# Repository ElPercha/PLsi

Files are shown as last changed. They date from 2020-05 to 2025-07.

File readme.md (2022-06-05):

## **PLsi Project Objectives**

Create a PLC & HMI with the following main characteristics:
+ To not require external systems such us Laptops or Cellphones to be programmed
+ To be used on Classroom for educational purposes, IoT applications or industrial low risk applications
+ Software and Hardware with Industrial performance and features
+ Forever Open Source and Open Hardware
+ Focus on Low Cost, V0 hardware estimated in less than [$20](hard/CPU/v0/)

-----------------------------------------------------------------------------------------

## Hardware Version 0

**Main characteristics:**

- Easy to build, no SMD components. DIY!
- ESP32 Processor
	+ Dual Core @240MHZ
	+ Wi-Fi connectivity
- 2.8" 320x240 Touchscreen Display
- 8 Hardware Inputs 5-24VDC Isolated with status led
- 6 Hardware Relay Outputs with status led. Max 10A, external fuse required
- Different combinations of Digital and Analog I/O using the same board
	+ Analog I/O range: 0-5V 
- Removable Terminal blocks
- USB 5Vdc main power supply
- I2C port for hardwired expansions
- SD Card slot
- 3D printed housing model including DIN rail mounting bracket

-----------------------------------------------------------------------------------------

## Firmware Version 0.00.03

**Main functionalities:**

- PLC Ladder Logic Instruction set: 
	+ 35 instructions
	+ Boolean instructions full set
	+ Timers and Counters full set
	+ Comparisons full set
	+ 16 bit math functions
- PLC Memory Areas:
	+ 2000 Marks (M)
	+ 200 Counters (C) 
	+ 300 Timers (T)
	+ 10000 Registers 16bits (D)
- PLC Program size:
	+ Up to 400 networks of 6x5 cells (12K boolean instructions)
	+ Up to 4 PLC programs stored on internal memory (max. 400 networks each)
- PLC Program Editor
	+ Online Edition (with PLC running)
	+ Row, Column and Network Editor
	+ Network Navigation
- PLC performance and control
	+ Scan time of 2.3ms for 2000 Boolean instructions
	+ Processor Core 1 runs Ladder Logic exclusively
	+ RUN/STOP with user confirmation
- Display functions:
	+ PLC Programming and debugging
	+ PLsi Configuration
	+ HMI
		- "Fix" version implemented (User cannot edit memory areas nor texts)
		- Screen 1: 8 Switches M500 to M507
		- Screen 2: 8 Buttons  M510 to M517
		- Screen 3: 8 User Input Values D500 to D507 
		- Screen 4: Local I/O visualization
		- Screen 5: 8 Indicators M520 to M527
- Communications:
	+ Wi-Fi configuration. Only DHCP
	+ SSID scanning functionality
- Firmware update via Web Page
- Analog Inputs and Outputs
	+ Selectable via Configuration page

-----------------------------------------------------------------------------------------

## PLsi v0 Documentation

Build your own unit: [PLsi v0 Hardware Manual](./doc/PLsi_v0_Hardware_Manual.pdf)

Wiring, configuration and programming: [PLsi v0 User Manual](./doc/PLsi_v0_User_Manual.pdf) (on contruction)

 <!---
Or watch the Youtube videos: 
 + [Building a PLsi v0 - EN](https://www.youtube.com)
 + [Building a PLsi v0 - SP](https://www.youtube.com)
 + [Configuring and Programming a PLsi v0 - EN](https://www.youtube.com)
 + [Configuring and Programming a PLsi v0 - SP](https://www.youtube.com)
-->
-----------------------------------------------------------------------------------------

## PLsi v0 Comparison with similar products

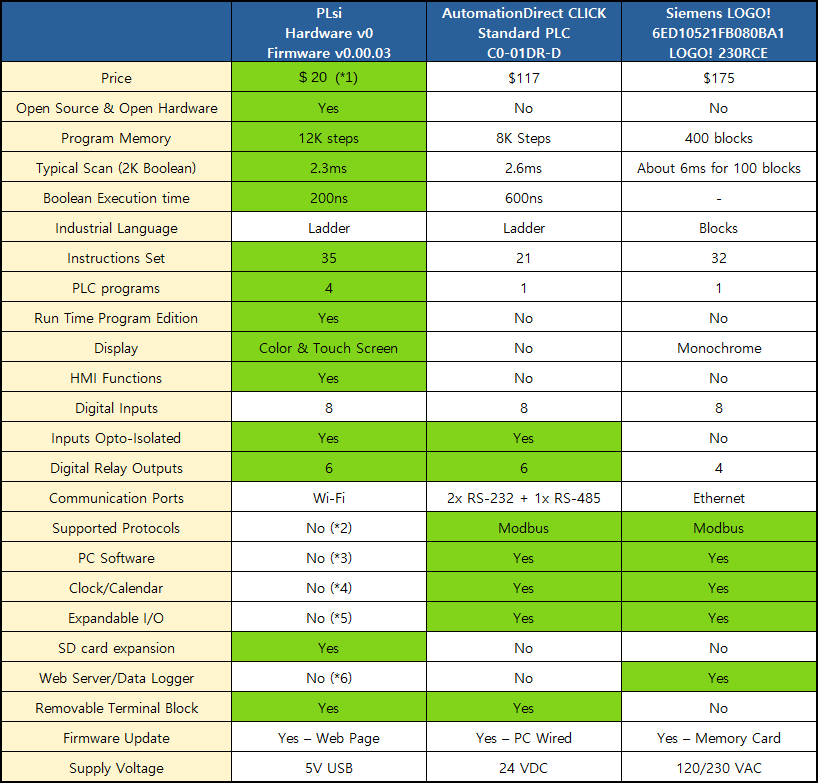
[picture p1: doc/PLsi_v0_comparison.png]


 1. DIY components pricing is included [here](hard/CPU/v0/)
 	- This pricing considers to purchase some bulk quantities
 2. Two industrial protocols are planned to be added in future releases
 	- S7 connection [Issue #26](https://github.com/ElPercha/PLsi/issues/26)
	- Modbus TCP [Issue #27](https://github.com/ElPercha/PLsi/issues/27)
 3. Not planned yet
 4. To be included on Hardware V1 [Issue #35](https://github.com/ElPercha/PLsi/issues/35)
 5. The I2C expansion port is available to connect wired expansions
 	- Wi-Fi expansion modules are also feasible
	- Not in the roadmap yet
 6. A Web HMI hosted on the PLsi unit is proposed on [Issue #42](https://github.com/ElPercha/PLsi/issues/42)

-----------------------------------------------------------------------------------------

## PLsi v0 Wiring diagrams

The PLsi board v0 is designed to support, at least, 2 different configurations:
 1. All Digital I/O
 	- 8 Digital Inputs
	- 6 Digital Relay Outputs
 2. Digital and Analog I/O
 	- 6 Digital Inputs
	- 4 Digital Relay Outputs
 	- 2 Analog Inputs 0-5V
 	- 2 Analog Outputs 0-5V
 
Check the [drawing](./hard/CPU/v0/board/schematic/PLsi_v0_Schematic.pdf) and the [Hardware Manual](./doc/PLsi_v0_Hardware_Manual.pdf) for more details on how to build the 2 different models using the same [board](./hard/CPU/v0/board/pictures/PLsi_board.svg)

### PLsi v0 Digital wiring diagram 



+ Supply Voltage: 5V 1A (recommended 2A)
	- Standard Micro USB type B connector
+ External fuse or fuses are required to protect the Outputs circuits
	- Fuse size has to be calculated considering a total MAX consumtion of 10A
+ SD Card is optional, it has no functionality implemented in Fimware v0.00.03
+ I2C Port is optional, it has no functionality implemented in Fimware v0.00.03

### PLsi v0 Analog wiring diagram



+ Analog Inputs and Outputs are not isolated

-----------------------------------------------------------------------------------------

## PLsi v0 Testing setup 

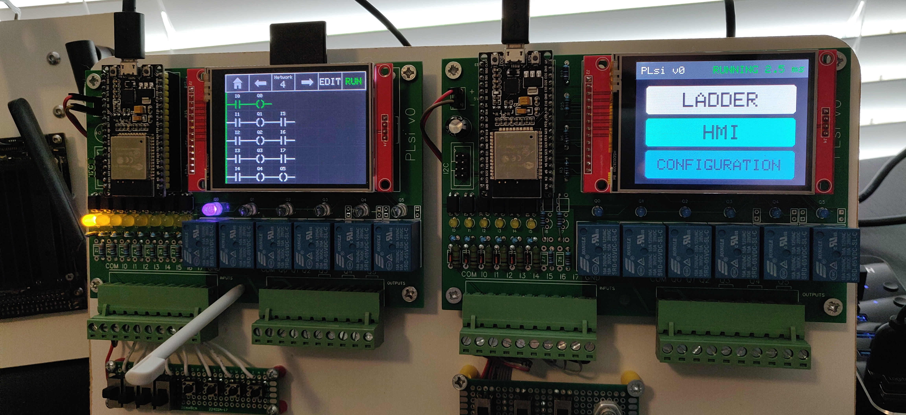
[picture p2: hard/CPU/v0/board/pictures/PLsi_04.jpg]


## PLsi v0 Housing

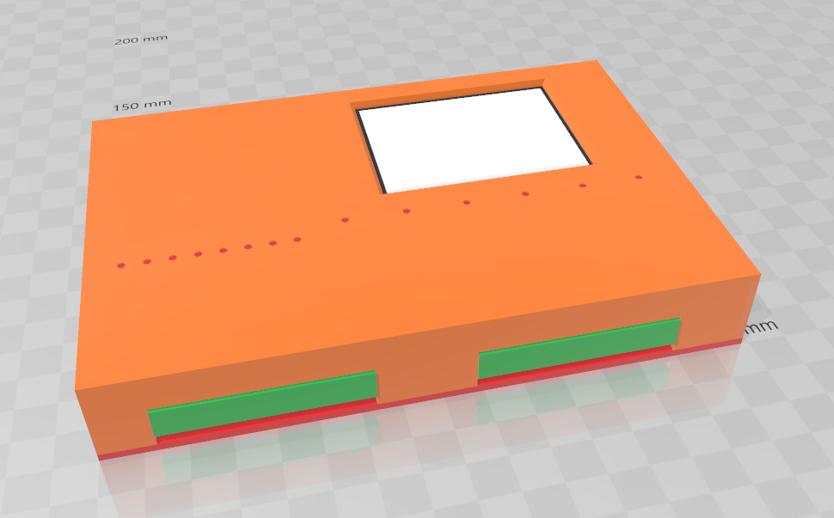
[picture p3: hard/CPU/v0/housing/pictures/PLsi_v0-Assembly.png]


## PLsi v0 Demo Panel

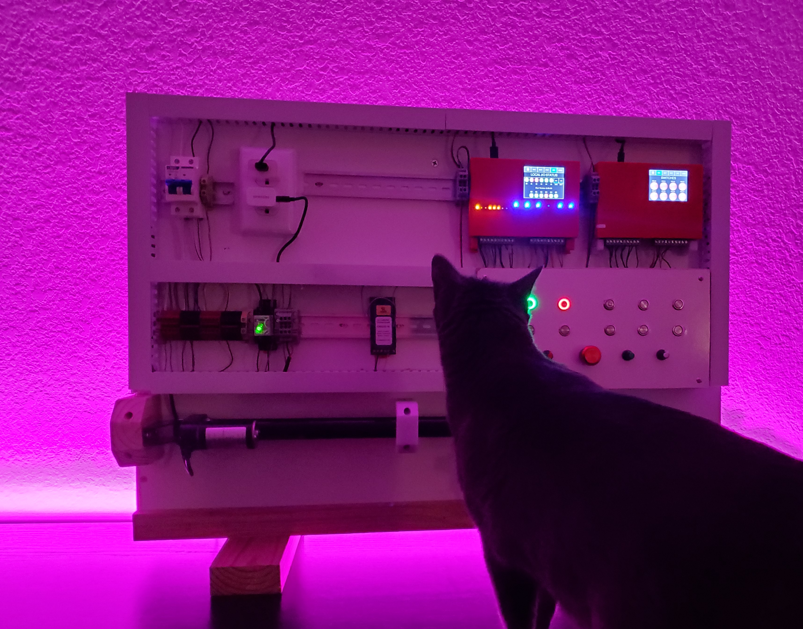
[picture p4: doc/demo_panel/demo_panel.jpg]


-----------------------------------------------------------------------------------------

Teach yourself and others how to program a PLC :)

-----------------------------------------------------------------------------------------

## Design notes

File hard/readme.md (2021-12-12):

For each Hardware version, 2 folders are available:

+ board
+ housing

Please, check the readme.md file inside each folder to have more details.

------------------------------------------------------------------

## PLsi v0 board



------------------------------------------------------------------

## PLsi v0 housing



------------------------------------------------------------------

## PLsi v0 din rail mounting bracket

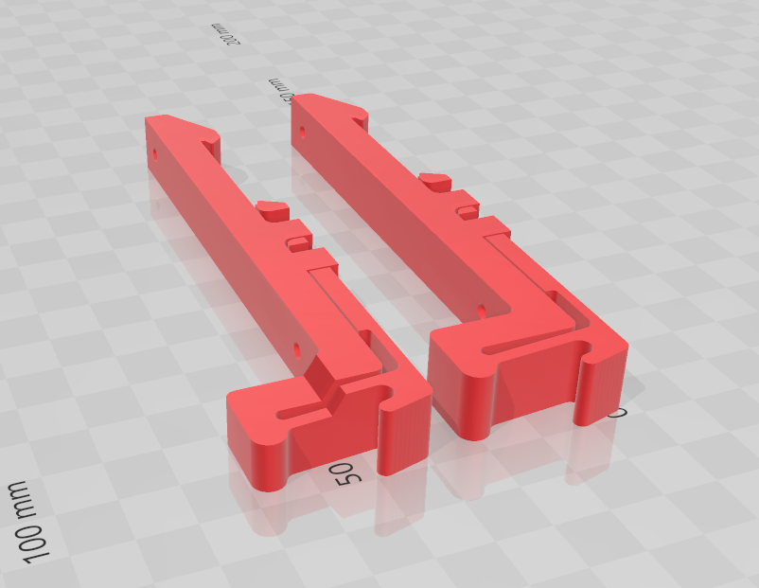
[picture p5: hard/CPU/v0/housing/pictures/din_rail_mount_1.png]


------------------------------------------------------------------

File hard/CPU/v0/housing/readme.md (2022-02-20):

The 3D design of the housing is composed by 2 models or main parts:
	"Housing Base" and "Housing Cover" 

You will also need 5 screws. Recommended size: #4 (3mm) x 1/2 inch Flat head.

The models were created using "Microsoft 3D builder" application, it is included in most of W10 Versions for free.
Ultimaker Cura Version: 4.8.0 was the Slicer used to create these files.
	<https://ultimaker.com/software/ultimaker-cura>

The housing is composed by 2 main and 1 optional parts:
	
	1  - housing base
	2a - housing cover (Revison E)
	2b - housing cover with Touch Pen (Revision F)
	3  - housing din rail (optional for DIN rail mounting)
		
For each part, 3 files are included in the "cura-slicer" folder:

	*.stl: It is a direct export from Microsoft 3D Builder
	*.3mf: It is the Cura project (unfortunatelly it uses the same extension as Microsoft 3D Builder) 
	*.gcode: It is the file to be imported in your 3D Printer

3D Print details:

	Housing Base:
		Printing Time: 5h

	Housing Cover:
		Printing Time: 9h

	Housing Cover with Pen:
		Printing Time: 9.5h

	Housing Din Rail Brackets:
		Printing Time: 10h

	3D Printer used:
		Creality3D Upgraded Ender-3 V2

	Main parameters for 3D Printer:
		Material: Generic PETG
		Nozzle diameter: 0.4mm
		Filament diameter: 1.75mm
		Speed: 50mm/s
		Speed first and last layer: 25mm/s
		Infill: 100%
		Nozzle Temp First layer: 230C
		Nozzle Temp: 225C
		Bed Temp: 80C
		Layer Height: 0.2mm
		Restracting distance: 3mm
		Restracting speed: 45mm/s
		Generate Support: true 
		Support placement: Everywhere 
		Support Overhang Angle: 45

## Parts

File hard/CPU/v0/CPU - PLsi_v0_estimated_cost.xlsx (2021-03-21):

All Items purchased on AliExpress includes shipping to Texas, US
Detail | Quantity | Unit Cost | Shipping | Unit Final Cost | Units per PLsi | PLsi Cost | Use by | Link | Type | Select the I/O | Max in v0
TFT Touchscreen Display 2.8 (240x320) + pen | 10 | 4.9300 | 8.33 | 5.7630 | 1 | 5.763 | HMI | https://www.aliexpress.com/item/32888213613.html?spm=a2g0s.9042311.0.0.27424c4d0qZ0bo | digital inputs | 8 | Max 8
ESP32 Wroom (38 pins) | 10 | 3.7600 | 2.63 | 4.0230 | 1 | 4.023 | CPU | https://www.aliexpress.com/item/32959541446.html | digital outputs | 6 | Max 6
Female 40pin header connector 2.54mm | 30 | 0.0950 | 0.58 | 0.1143 | 1.7 | 0.1944 | HMI and CPU | https://www.aliexpress.com/item/32861400498.html?spm=a2g0s.9042311.0.0.27424c4d0qZ0bo | analog inputs | 0 | Max 2
Male 40pin header connector 2.54mm | 10 | 0.0570 | 0.58 | 0.1150 | 0.1 | 0.0115 | HMI and CPU | https://www.aliexpress.com/item/32864438850.html?spm=a2g0s.9042311.0.0.27424c4dtHH5qT | analog outputs | 0 | Max 2
Capacitor | 10 | 0.1530 | 0 | 0.1530 | 1 | 0.153 | Power supply | https://www.aliexpress.com/item/32812085542.html?spm=a2g0s.9042311.0.0.27424c4d0qZ0bo | Total Outs | 8 | Max 8
leds 3mm | 1 | 0.0053 | 0 | 0.0053 | 14 | 0.07448 | digital inputs / outputs | https://www.aliexpress.com/item/32749396579.html?spm=a2g0s.9042311.0.0.27424c4dNpntna | Total Outs | 6 | Max 6
Relays 5V | 50 | 0.2734 | 0 | 0.2734 | 6 | 1.6404 | digital outputs | https://www.aliexpress.com/item/32909532466.html?spm=a2g0s.9042311.0.0.27424c4demAhCt
ULN2003 (7x relay driver) | 10 | 0.0890 | 0 | 0.0890 | 1 | 0.089 | digital outputs | https://www.aliexpress.com/item/32769537810.html?spm=a2g0s.9042311.0.0.27424c4d0qZ0bo
R 330 ohm | 1 | 0.0096 | 0 | 0.0096 | 6 | 0.0576 | digital output | https://www.aliexpress.com/item/32948115055.html?spm=a2g0s.9042311.0.0.27424c4d0qZ0bo
Optocoupler 4 pins | 50 | 0.0190 | 0.42 | 0.0274 | 8 | 0.2192 | digital inputs | https://www.aliexpress.com/item/32835155712.html?spm=a2g0s.9042311.0.0.27424c4d0qZ0bo
Zener 5,1V 0.5W | 100 | 0.0130 | 0 | 0.0130 | 8 | 0.104 | digital inputs | https://www.aliexpress.com/item/32865106042.html?spm=a2g0s.9042311.0.0.27424c4d0qZ0bo
R 510 ohm | 1 | 0.0096 | 0 | 0.0096 | 8 | 0.0768 | digital inputs | https://www.aliexpress.com/item/32948115055.html?spm=a2g0s.9042311.0.0.27424c4d0qZ0bo
R 1K 1W | 1 | 0.0176 | 0 | 0.0176 | 8 | 0.1408 | digital inputs | https://www.aliexpress.com/item/32914704172.html?spm=a2g0s.9042311.0.0.27424c4dihQVHs
R 10K | 1 | 0.0096 | 0 | 0.0096 | 8 | 0.0768 | digital inputs | https://www.aliexpress.com/item/32948115055.html?spm=a2g0s.9042311.0.0.27424c4d0qZ0bo
Rail-to-Rail TLV2462CP DIP8 (*1) | 10 | 2.5440 | 8 | 3.3440 | 0 | 0 | analog output | Mouser
R1 Voltage amp 3k3 | 1 | 0.0096 | 0 | 0.0096 | 0 | 0 | analog output | https://www.aliexpress.com/item/32948115055.html?spm=a2g0s.9042311.0.0.27424c4d0qZ0bo
R2 Voltage amp 5k1 | 1 | 0.0096 | 0 | 0.0096 | 0 | 0 | analog output | https://www.aliexpress.com/item/32948115055.html?spm=a2g0s.9042311.0.0.27424c4d0qZ0bo
1N4148 | 200 | 0.0054 | 0 | 0.0054 | 0 | 0 | analog inputs | https://www.aliexpress.com/item/2025724181.html?spm=a2g0s.9042311.0.0.27424c4d0qZ0bo
Terminal blocks 10 poles 5.08mm | 20 | 0.6995 | 0 | 0.6995 | 2 | 1.399 | I/O | https://www.aliexpress.com/item/32620069944.html?spm=a2g0s.9042311.0.0.27424c4d0qZ0bo
Board 100mm x 150mm | 10 | 1.4100 | 11.02 | 2.5120 | 1 | 2.512 | Main board | https://jlcpcb.com/
 |  |  |  |  | Total Price | 16.53
*1 This price is from Mouser.com, it can be lowered by purchasing in AliExpress |  |  |  | Total Price Digital version |  | 16.53
 |  |  |  | Total Price Analog version |  | 19.24

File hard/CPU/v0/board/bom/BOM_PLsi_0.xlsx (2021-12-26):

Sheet: v0 - Digital
Item | Component TAG | Description | Quantity | Comment
1 | U1 | NodeMCU_ESP32S | 1 | CPU ESP32
2 | U2 | Touch Screen Display | 1 | TFT Touch Display 2.8TFT_SPI_240*320
3 | U14 | ULN2003N | 1 | To drive Outputs relays
4 | INPUTS, OUTPUTS | 5.08 x 10 Terminal block | 2 | Main I/O connections
5 | U2 – SD Card conenction pins | Dupont 2.54mm Male strip | 4 pins | Touch Screen Display SD Card connection
6 | U1 and U2 – Socket | Dupont 2.54mm Female strip | 2 x 40 pins | Female sockets for ESP32 and Display
7 | 5V (Optional) | Dupont 3 pins male | 3 pins | Optional – External 5V use
8 | P4 (Optional) | HDR-IDC-2.54-2X4P | 1 | Optional - I2C expansion
9 | C2 | Capacitor 1000uF 9V | 1 | Capacitor
10 | OPTO1, OPTO2, OPTO3, OPTO4, OPTO5, OPTO6, OPTO7, OPTO8 | Optocupler PC817 | 8 | Optocouplers
11 | Z1, Z2, Z3, Z4, Z5, Z6, Z7, Z8 | Diode 5v1 – Zenner 1w | 8 | Digital Inputs
12 | I0, I1, I2, I3, I4, I5, I6, I7 | Leds 3mm Color 1 | 8 | Leds digital inputs
13 | Q0, Q1, Q2, Q3, Q4, Q5 | Leds 3mm Color 2 | 6 | Leds digital outputs
14 | R3, R6, R9, R12, R13, R16, R19, R24 | Resistor 10k | 8 | Resistors digital inputs
15 | R1, R5, R8, R11, R14, R17, R20, R23 | Resistor 1K x 1/2W | 8 | Resistors digital inputs
16 | R2, R4, R7, R10, R15, R18, R21, R22 | Resistor 510 ohms | 8 | Resistors digital inputs
17 | R31, R32, R33, R34, R35, R36 | Resistor 330 ohms | 6 | Digital outputs leds
18 | RELAY1, RELAY2, RELAY3, RELAY4, RELAY5, RELAY6 | SRD-05VDC-SL-C | 6 | Output Relays

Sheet: v0 - Analog
Item | Component TAG | Description | Quantity | Comment
1 | U1 | NodeMCU_ESP32S | 1 | CPU ESP32
2 | U2 | Touch Screen Display | 1 | TFT Touch Display 2.8TFT_SPI_240*320
3 | U14 | ULN2003N | 1 | To drive Outputs relays
4 | INPUTS, OUTPUTS | 5.08 x 10 Terminal block | 2 | Main I/O connections
5 | U2 – SD Card conenction pins | Dupont 2.54mm Male strip | 4 pins | Touch Screen Display SD Card connection
6 | U1 and U2 – Socket | Dupont 2.54mm Female strip | 2 x 40 pins | Female sockets for ESP32 and Display
7 | 5V (Optional) | Dupont 3 pins male | 3 pins | Optional – External 5V use
8 | P4 (Optional) | HDR-IDC-2.54-2X4P | 1 | Optional - I2C expansion
9 | C2 | Capacitor 1000uF 9V | 1 | Capacitor
10 | OPTO1, OPTO2, OPTO3, OPTO4, OPTO5, OPTO6 | Optocupler PC817 | 6 | Optocouplers
11 | Z1, Z2, Z3, Z4, Z5, Z6 | Diode 5v1 – Zenner 1w | 6 | Digital Inputs
12 | I0, I1, I2, I3, I4, I5 | Leds 3mm Color 1 | 6 | Leds digital inputs
13 | Q0, Q1, Q2, Q3 | Leds 3mm Color 2 | 4 | Leds digital outputs
14 | R3, R6, R9, R12, R19, R24 | Resistor 10k | 6 | Resistors digital inputs
15 | R1, R5, R8, R11, R20, R23 | Resistor 1K x 1/2W | 6 | Resistors digital inputs
16 | R2, R4, R7, R10, R21, R22 | Resistor 510 ohms | 6 | Resistors digital inputs
17 | R31, R32, R33, R34 | Resistor 330 ohms | 4 | Digital outputs leds
18 | RELAY1, RELAY2, RELAY3, RELAY4 | SRD-05VDC-SL-C | 4 | Output Relays
19 | D1, D2, D3, D4 | Diode 1N4148 | 4 | Analog Inputs protection
20 | R25, R26, R37, R38, R39, R40 | Resistor 10k 1% | 6 | Analog Inputs ⅓ divisor
21 | R27,R29 | Resistor 5k1 1% | 2 | Analog outputs gain divisor
22 | R28,R30 | Resistor 3k3 1% | 2 | Analog outputs gain divisor
23 | U11 | TLV2462CP | 1 | Analog outputs Rail to Rail Op Amplifier

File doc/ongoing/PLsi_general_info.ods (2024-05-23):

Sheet: Instruction Codes
Code | Mnemonic | Canvas | Programmed | Group | Heigth | Width | Description | Instructions to be implemented
0 | NOP |  |  |  | 1 | 1 | No instruction is present in this cell. Empty Cell
1 | CON | drawConn | execConn | Basic | 1 | 1 | Direct connection | SUB MUL, etc for floating point or Int (32 bits) |  |  | Visualization problem
2 | INV | drawNeg | execNeg | Basic | 1 | 1 | Direct connection – Inverted | CONVERSION | general conversion blocks, specially between 16bit and real
3 | NO | drawNO | execNO | Basic | 1 | 1 | Normal Open Contact
4 | NC | drawNC | execNC | Basic | 1 | 1 | Normal Closed Contact | PID | only REAL ? |  | Control
5 | RE | drawRE | execRE | Basic | 1 | 1 | Rise Edge contact | RAMP | only REAL ? |  | Control
6 | FE | drawFE | execFE | Basic | 1 | 1 | Fall Edge Contact | INTEGRATE | only REAL |  | Control | Integral calculation
7 | C | drawCoil | execCoil | Basic | 1 | 1 | Coil | DERIVATIVE | only REAL |  | Control | derivate the input
8 | L | drawCoilL | execCoilL | Basic | 1 | 1 | Latch Coil (Set) | HYSTERESIS | only REAL |  | Control | bool out between 3 values real
9 | U | drawCoilU | execCoilU | Basic | 1 | 1 | Unlatch Coil (Reset) | ABS | only REAL |  | Advanced Math
10 | TON | drawTon | execTON | Timers | 2 | 1 | Timer On | SQRT | only REAL |  | Advanced Math
11 | TOFF | drawToff | execTOFF | Timers | 2 | 1 | Timer Off | LN | only REAL |  | Advanced Math
12 | TP | drawTp | execTP | Timers | 2 | 1 | Timer Pulse | LOG | only REAL |  | Advanced Math
13 | CTU | drawCTU | execCTU | Counters | 2 | 1 | Counter Up | EXP | only REAL |  | Advanced Math
14 | CTD | drawCTD | execCTD | Counters | 2 | 1 | Counter Down | SIN | only REAL |  | Trigonometry
15 | MOVE | drawMove | execMOVE | Basic Math | 2 | 1 | Move | COS | only REAL |  | Trigonometry
16 | SUB | drawSUB | execSUB | Basic Math | 3 | 1 | 16bit int Subtraction | TAN | only REAL |  | Trigonometry
17 | ADD | drawADD | execADD | Basic Math | 3 | 1 | 16bit int Addition | ASIN | only REAL |  | Trigonometry
18 | MUL | drawMUL | execMUL | Basic Math | 3 | 1 | 16bit int Multiplication | ACOS | only REAL |  | Trigonometry
19 | DIV | drawDIV | execDIV | Basic Math | 3 | 1 | 16bit int Division | ATAN | only REAL |  | Trigonometry
20 | MOD | drawMOD | execMOD | Basic Math | 3 | 1 | 16bit int Module of division (remainder) | RAN | only REAL |  | Random value generator
21 | SHL | drawSHL | execSHL | Binary (Bitwise) | 2 | 1 | Shift left | FIFO
22 | SHR | drawSHR | execSHR | Binary (Bitwise) | 2 | 1 | Shift right | LIFO
23 | ROL | drawROL | execROL | Binary (Bitwise) | 2 | 1 | Rotate Left | RBUF | Ring Buffer
24 | ROR | drawROR | execROR | Binary (Bitwise) | 2 | 1 | Rotate Right | RTI | Real to Integer | TYPE CONVERSION
25 | AND | drawAND | execAND | Binary (Bitwise) | 3 | 1 | Bitwise And | ITR | Integer to Real | TYPE CONVERSION
26 | OR | drawOR | execOR | Binary (Bitwise) | 3 | 1 | Bitwise Or | TIME and DATE | schedule management
27 | XOR | drawXOR | execXOR | Binary (Bitwise) | 3 | 1 | Bitwise Xor |  | arithmetic on Time and Date
28 | NOT | drawNOT | execNOT | Binary (Bitwise) | 2 | 1 | Bitwise Not
29 | EQ | drawEQ | execEQ | Comparison | 2 | 1 | Equal than | String Functions
30 | GT | drawGT | execGT | Comparison | 2 | 1 | Greater than
31 | GE | drawGE | execGE | Comparison | 2 | 1 | Greater or Equal than | SEL | not really needed |  | Selection | Select between 2 inputs
32 | LT | drawLT | execLT | Comparison | 2 | 1 | Less than | MAX | not really needed |  | Selection | Max between 2 inputs
33 | LE | drawLE | execLE | Comparison | 2 | 1 | Less or Equal than | MIN | not really needed |  | Selection | Min between two inputs
34 | NE | drawNE | execNE | Comparison | 2 | 1 | Not equal | LIM | not really needed |  | Selection | Limit for a given input between two threshold
35 |  |  |  |  |  |  |  | MUX | not really needed |  | Selection | Select between 2 inputs or more
36
37
38
39
40
41
42
43
44
45
46
 |  |  |  |  |  |  |  | PID stands for proportional, integral, derivative control. I’ll break it down: P: if you’re not where you want to be, get there. I: if you haven’t been where you want to be for a long time, get there faster D: if you’re getting close to where you want to be, slow down.

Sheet: Memory Types
Tag | Type | Range | DataType Code | Quantity | Example | Description | Comment
M | Byte | True / False | 0 | 2000 | M0.0 | Internal Marks or Flags | Image duplicated to get the Edges with easy user programming, no extra bit required
Q | Byte | True / False | 1 | 200 | Q0.0 | Digital Outputs
I | Byte | True / False | 2 | 200 | I0.0 | Digital Inputs
Cd | Byte | True / False | 3 | 200 | Cd1 Cd199 | Counter Activation bit
Cr | Byte | True / False | 4 | 200 | Cr1 Cr199 | Counter Running bit
Td | Byte | True / False | 5 | 300 | Td1 Td200 | Timer Activation bit
Tr | Byte | True / False | 6 | 300 | Tr1 Tr200 | Timer Running bit
IW | uint16_t | 0 – 4095 (12 bits) | 7 | 50 | IW0 IW56 | Analog Inputs
QW | uint16_t | 0 – 4095 (12 bits) | 8 | 50 | QW1 QW17 | Analog Outputs
C | uint16_t | 0 – 65535 | 9 | 200 | C1 C154 | Counter Register
T | struct | 0 – 65535 | 10 | 200 | T1 T34 | Timer Register
D | int16_t | -32767 to 32767 | 11 | 10000 | D500 D1 | Regular Integer Registers
K | - | -32767 to 32767 | 12 | -- | K0 K-30888 | Integer constant value
R | Real |  | 13 | 2000 | R1 R1523 | Floating Points Registers | Not yet implemented
KR | - |  | 14 | -- | KR(min real) KR(max real) | Real Constant value | Not yet implemented

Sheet: IO_2
 | Hardware connection
 | Display Connector / SPI
 | USB / TX-RX
 | IO available
 | Flash Control
 | IO Expansion
 | SD card
 | Embedded Functions
Index | WROOM32 DevKitC | PLsi v0 | PLsi v1
1 | 3V3 | -- | --
2 | EN | -- | TFT_RST
3 | GPIO36 | In7 / analog in 1 | Sensor VP
4 | GPIO39 | In6 / analog in 0 | Sensor VN
5 | GPIO34 | in0 | PHOTOCELL
6 | GPIO35 | in1 | Connector I/O
7 | GPIO32 | in2 | Touch GT911 - SCL
8 | GPIO33 | Display – RST | Touch GT911 – SDA
9 | GPIO25 | out5 / analog out 1 | Touch GT911 – RST
10 | GPIO26 | out4 / analog out 0 | AUDIO OUT
11 | GPIO27 | Display – DataCommand | Display – BackLight
12 | GPIO14 | Display – SPI CS | Display ST7789 – SPI SCK
13 | GPIO12 | Display | Display ST7789 – SPI SDO
14 | GND | -- | --
15 | GPIO13 | in3 | Display ST7789 – SPI SDA
16 | SD2 | Flash Control | Flash Control
17 | SD3 | Flash Control | Flash Control
18 | CMD | Flash Control | Flash Control
19 | 5V | -- | --
20 | CLK | Flash Control | Flash Control
21 | SD0 | Flash Control | Flash Control
22 | SD1 | Flash Control | Flash Control
23 | GPIO15 | out3 | Display ST7789 – SPI CS
24 | GPIO2 | out2 | Display ST7789 – WR / A0
25 | GPIO0 | in5 | Boot Button
26 | GPIO4 | in4 | LED RGB OUT
27 | GPIO16 | out1 | LED RGB OUT
28 | GPIO17 | out0 | LED RGB OUT
29 | GPIO5 | SD Card CS | SD Card CS
30 | GPIO18 | Display – CLK | SD Card CLK
31 | GPIO19 | Display – MISO | SD Card MISO
32 | GND | -- | --
33 | GPIO21 | I2C SDA | I2C SDA (Connector I/O)
34 | GPIO3 | USB – RX | USB – RX
35 | GPIO1 | USB – TX | USB – TX
36 | GPIO22 | I2C SCL | I2C SCL (Connector I/O)
37 | GPIO23 | Display – MOSI | SD Card MOSI
38 | GND | -- | --

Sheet: IO
 |  | Display Connector / SPI
 |  | USB / TX-RX
 |  | IO available
 |  | Flash Control
 |  | IO Expansion
 |  | SD card CS
PLsi v0 | WROOM32 DevKitC | Index | WROOM32 DevKitC | PLsi v0
 | 3V3 | 1 | GND
 | EN | 2 | GPIO23 (Display)
In7 / analog in 1 | GPIO36 (ADC1 CH0) | 3 | GPIO22 | I2C SCL
In6 / analog in 0 | GPIO39 | 4 | GPIO1 TX
in0 | GPIO34 | 5 | GPIO3 RX
in1 | GPIO35 | 6 | GPIO21 | I2C SDA
in2 | GPIO32 | 7 | GND
 | GPIO33 (Display) | 8 | GPIO19 (Display)
out5 / analog out 1 | GPIO25 | 9 | GPIO18 (Display)
out4 / analog out 0 | GPIO26 | 10 | GPIO5 (SD CS) | SD_CS
 | GPIO27 (Display) | 11 | GPIO17 | out0
 | GPIO14 (Display) | 12 | GPIO16 | out1
 | GPIO12 (Display) | 13 | GPIO4 | in4
 | GND | 14 | GPIO0 | in5
in3 | GPIO13 | 15 | GPIO2 | out2
 | SD2 | 16 | GPIO15 | out3
 | SD3 | 17 | SD1
 | CMD | 18 | SD0
 | 5V | 19 | CLK

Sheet: Network
 |  |  |  | Network Structure:
 |  | BARS 0 |  | BARS 1 |  | BARS 2 |  | BARS 3 |  | BARS 4
 | COLUMN 0 | FLAGS 0 | COLUMN 1 | FLAGS 1 | COLUMN 2 | FLAGS 2 | COLUMN 3 | FLAGS 3 | COLUMN 4 | FLAGS 4 | COLUMN 5
ROW 0 | Cell (0,0)
ROW 1
ROW 2
ROW 3 |  |  | Cell (3,1)
ROW 4 |  |  |  |  |  |  |  |  |  |  | Cell (4,5)
 |  |  |  | Cell Structure:
 |  |  |  | Byte 1 | Byte 0
 | Networks[0].Cells[0][0].Code |  |  | Instruction Code |  | uint16_t
 | Networks[0].Cells[0][0].Data |  |  | Data or *Data Pointer |  | int16_t
 | Networks[0].Cells[0][0].Type |  |  | Data Type |  | uint16_t

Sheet: Colors
15 | 14 | 13 | 12 | 11 | 10 | 9 | 8 | 7 | 6 | 5 | 4 | 3 | 2 | 1 | 0
 |  |  |  |  |  |  |  |  |  |  |  |  |  |  |  | Custom colors
 |  |  |  |  | 1 | 1 | 1 | 1 | 1 | 1 | 1 | 1 | 1 | 1 | 1 | cyan
 |  |  |  |  | 1 | 0 | 0 | 1 | 1 | 1 | 1 | 1 | 1 | 1 | 1 | aqua
 |  |  |  |  | 1 | 0 | 1 | 1 | 1 | 1 | 1 | 1 | 1 | 1 | 1 | cyanl
1 | 1 | 1 | 1 | 1 | 0 | 0 | 0 | 1 | 1 | 1 | 1 | 1 | 1 | 1 | 1 | pink
0 | 1 | 1 | 1 | 1 | 0 | 0 | 0 | 1 | 1 | 1 | 0 | 1 | 1 | 1 | 1 | purple
0 | 1 | 1 | 0 | 0 | 0 | 0 | 0 | 1 | 1 | 0 | 0 | 1 | 0 | 0 | 0 | purple1
0 | 0 | 1 | 0 | 0 | 0 | 0 | 0 | 0 | 1 | 1 | 0 | 0 | 1 | 0 | 0 | purple2
0 | 0 | 1 | 0 | 0 | 0 | 0 | 0 | 0 | 0 | 1 | 0 | 0 | 0 | 0 | 0 | brown
0 | 0 | 1 | 0 | 0 | 0 | 0 | 0 | 0 | 0 | 0 | 0 | 0 | 0 | 0 | 0 | brown1
0 | 0 | 1 | 1 | 1 | 0 | 0 | 1 | 0 | 0 | 1 | 0 | 0 | 0 | 0 | 0 | yellow1
0 | 1 | 1 | 1 | 1 | 0 | 1 | 1 | 1 | 1 | 1 | 0 | 0 | 0 | 0 | 0 | yellow2
1 | 1 | 0 | 0 | 0 | 1 | 1 | 1 | 0 | 1 | 1 | 1 | 1 | 1 | 0 | 0 | White1
1 | 1 | 0 | 0 | 0 | 1 | 1 | 0 | 1 | 1 | 1 | 1 | 1 | 0 | 0 | 0 | White2
1 | 0 | 0 | 0 | 0 | 1 | 0 | 1 | 0 | 0 | 0 | 1 | 0 | 0 | 0 | 0 | White3
0 | 0 | 0 | 0 | 0 | 0 | 0 | 0 | 0 | 0 | 0 | 0 | 0 | 1 | 0 | 0 | darkblue
0 | 0 | 0 | 0 | 0 | 0 | 0 | 0 | 1 | 1 | 1 | 0 | 0 | 0 | 0 | 0 | LightGreen

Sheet: ConfigurationMenu
PAGE NAME | DETAILS | PAGE NAME | DETAILS | PAGE NAME |  | DETAILS | PAGE NAME | DETAILS | COMMENTS
PAGE_MainConfig | CONFIGURATION | PAGE_ConfigNetwork | NETWORK | PAGE_ConfigWiFi |  | CONFIGURE SSID AND PASS | PAGE_ScanWiFi | SCAN WIFI | ip and connected status + Scan Networks
 |  |  |  | PAGE_ConfigModbusTCP |  | Configure Modbus Server and Clients
 |  |  |  | PAGE_ConfigS7 |  | S7 CONNECTION |  |  | Configuration and status
 |  |  |  | PAGE_WebServer |  | WEB SERVER |  |  | Configuration and status
 |  |  |  |  |  |  |  |  | Enable to see info and control?
 |  | PAGE_ConfigPLC | PLC | PAGE_ConfigProgram |  | SELECT PROGRAM NUMBER
 |  |  |  |  | SD | PROGRAM MANAGEMENT |  |  | CLEAR / COPY / PASTE PROGRAMS FROM TO SD
 |  |  |  |  |  | MAX NETWORKS |  |  | PER PROGRAM?
 |  |  |  |  |  | SCAN TIME |  |  | ACTUAL MIN AND MAX |  | FIX
 |  |  |  |  |  | WATCHDOG
 |  |  |  |  |  | SYSTEM SIGNALS |  |  | CLOCK of several frequencies – Scan Time – Etc. Assignment to Memory accessible in program
 |  |  |  |  |  | QUANTITY OF FORCES
 |  |  |  |  |  | TAGS
 |  |  |  |  |  | USAGE |  |  | show datatypes ranges and quantity |  |  | Show usage in program for datatype selected
 |  | pageConfigIO | I/O & DEVICES |  |  | DIGITAL INPUTS FILTER
 |  |  |  |  |  | ANALOG INPUTS FILTER AND SCALING
 |  |  |  |  |  | ANALOG OUTPUTS FILTER AND SCALING
 |  |  |  |  |  | HIGH SPEED INPUTS COUNTERS
 |  |  |  |  |  | REMOTES CONFIGURATION AND STATUS
 |  | PAGE_ConfigHMI | HMI |  |  | SCREEN CONFIGURATION
 |  |  |  |  |  | ALARMS CONFIGURATION
 |  | PAGE_ConfigSystem | SYSTEM |  |  | PROJECT INFO |  |  | User introduce comments
 |  |  |  |  |  | PLsi INFO |  |  | FIRMWARE VERSION |  | HARDWARE VERSION |  | ANALOG OR DIGITAL | ETC
 |  |  |  | PAGE_ConfigFirmware |  | FIRMWARE UPDATE
 |  |  |  |  |  | TS CALIBRATION
 |  |  |  |  | SD | SETTINGS MANAGEMENT |  |  | SAVE / RETRIEVE TO/FROM SD
 |  |  |  |  |  | UPTIME |  |  | RTOS task status
 |  |  |  |  |  | MEMORY |  |  | STATUS OF RAM CURRENT & HISTORY
 |  |  |  |  | SD | STATUS OF SD SIZE FREE SPACE & FORMAT? |  |  |  | view files?
 |  |  |  |  |  | DATE AND TIME
 |  |  |  |  | SD | LOG
 |  |  |  |  |  | VERBOSITY LEVEL ON SERIAL PORT
 |  |  |  |  |  | FACTORY RESET

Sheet: Instructions
 | Memory allocation in Network structure for different instructions
For blocks (instructions) that uses more than one cell, “Instruction Index” has the index for this cell, example:
Used by Logic Evaluator and Logic Editor
 |  | Cell 1 | ADD | Instruction Index = 0
 |  | Cell 2 |  | Instruction Index = 1
 |  | Cell 3 |  | Instruction Index = 2
 |  | Byte 1 | Byte 0
TIMER | Networks[0].Cells[0][0].Code | Instruction Code |  | Uint 16 | Instruction Code
 | Networks[0].Cells[0][0].Data | *Data Pointer |  | Int 16 | Pointer to T[x] array, actual value of Timer in ms (32 bits unsigned long)
 | Networks[0].Cells[0][0].Type | Data Type |  | Uint 16 | Always 10 for Timers
 |  | Byte 1 | Byte 0 |  |  |  |  | Byte 1 |  |  |  | Byte 1 |  |  |  | Byte 0
Second cell | Networks[0].Cells[0][0].Code | Instruction Code |  | Uint 16 | Same Instruction Code + Index of instructions bigger than one cell |  |  | Index | 0 | 0 | 0 | Instruction Code 12 bits | I | I | I | I
 | Networks[0].Cells[0][0].Data | *Data Pointer |  | Int 16 | Setpoint of Timer |  |  | 0 | 0 | 0 | 0 |  | Instruction is simple height cell or it is the first cell of a multiple cells instruction
 |  |  |  |  |  |  |  | x | 0 | 0 | 1 |  | Second cell for a multiple cell height instruction
 | Networks[0].Cells[0][0].Type | Data Type |  | Uint 16 | Scale for Timer. Direct division: | 1 | ms | x | 0 | 1 | 0 |  | Third cell for a multiple cell height instruction
 |  |  |  |  |  | 10 | 0.01 sec | x | 0 | 1 | 1 |  | Fourth cell for a multiple cell height instruction
 |  |  |  |  |  | 100 | 0.1 sec | x | 1 | 0 | 0 |  | Fifth cell for a multiple cell height instruction
 |  |  |  |  |  | 1000 | sec | 1 | x | x | x |  | Second column for a multiple columns instruction
 |  |  |  |  |  | 60000 | min
COUNTER | Networks[0].Cells[0][0].Code | Instruction Code |  | Uint 16 | Instruction Code
 | Networks[0].Cells[0][0].Data | *Data Pointer |  | Int 16 | Pointer to T[x] array, actual value of Timer in ms (32 bits unsigned long)
 | Networks[0].Cells[0][0].Type | Data Type |  | Uint 16 | Always 9 for Counters
Second cell | Networks[0].Cells[0][0].Code | Instruction Code |  | Uint 16 | Same Instruction Code + Index of instructions bigger than one cell
 | Networks[0].Cells[0][0].Data | *Data Pointer |  | Int 16 | Setpoint of Counter
 | Networks[0].Cells[0][0].Type | Data Type |  | Uint 16 | Not used
SUB, ADD | Networks[0].Cells[0][0].Code | Instruction Code |  | Uint 16 | Instruction Code
MUL, DIV
 | Networks[0].Cells[0][0].Data | *Data Pointer |  | Int 16 | Pointer to First Data
 | Networks[0].Cells[0][0].Type | Data Type |  | Int 16 | Type for first data
Second cell | Networks[0].Cells[0][0].Code | Instruction Code |  | Uint 16 | Same Instruction Code + Index of instructions bigger than one cell
 | Networks[0].Cells[0][0].Data | *Data Pointer |  | Int 16 | Pointer to Second Data
 | Networks[0].Cells[0][0].Type | Data Type |  | Int 16 | Type for second data
Third | Networks[0].Cells[0][0].Code | Instruction Code |  | Uint 16 | Same Instruction Code + Index of instructions bigger than one cell
 | Networks[0].Cells[0][0].Data | *Data Pointer |  | Int 16 | Pointer to Third data
 | Networks[0].Cells[0][0].Type | Data Type |  | Int 16 | Type for third data

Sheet: Canvas
 | 1 | 2 | 3 | 4 | 5 | 6 | 7 | 8 | 9 | 10 | 11 | 12 | 13 | 14 | 15 | 16 | 17 | 18 | 19 | 20 | 21 | 22 | 23 | 24 | 25 | 26 | 27 | 28
1
2
3
4
5
6
7
8
9
10
11
12
13
14
15
16
17
18
19
20
21
22
23
24
25
26
27
28
29
30
31
32
33
34
35
36
37
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

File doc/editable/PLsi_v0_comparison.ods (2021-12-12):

 | PLsi | AutomationDirect CLICK | Siemens LOGO!
 | Hardware v0 | Standard PLC | 6ED10521FB080BA1
 | Firmware v0.00.03 | C0-01DR-D | LOGO! 230RCE
 | Page-1
Price | $ 20 (*1) | $117 | $175
Open Source & Open Hardware | Yes | No | No
Program Memory | 12K steps | 8K Steps | 400 blocks
Typical Scan (2K Boolean) | 2.3ms | 2.6ms | About 6ms for 100 blocks
Boolean Execution time | 200ns | 600ns | -
Industrial Language | Ladder | Ladder | Blocks
Instructions Set | 35 | 21 | 32
PLC programs | 4 | 1 | 1
Run Time Program Edition | Yes | No | No
Display | Color & Touch Screen | No | Monochrome
HMI Functions | Yes | No | No
Digital Inputs | 8 | 8 | 8
Inputs Opto-Isolated | Yes | Yes | No
Digital Relay Outputs | 6 | 6 | 4
Communication Ports | Wi-Fi | 2x RS-232 + 1x RS-485 | Ethernet
Supported Protocols | No (*2) | Modbus | Modbus
PC Software | No (*3) | Yes | Yes
Clock/Calendar | No (*4) | Yes | Yes
Expandable I/O | No (*5) | Yes | Yes
SD card expansion | Yes | No | No
Web Server/Data Logger | No (*6) | No | Yes
Removable Terminal Block | Yes | Yes | No
Firmware Update | Yes – Web Page | Yes – PC Wired | Yes – Memory Card
Supply Voltage | 5V USB | 24 VDC | 120/230 VAC

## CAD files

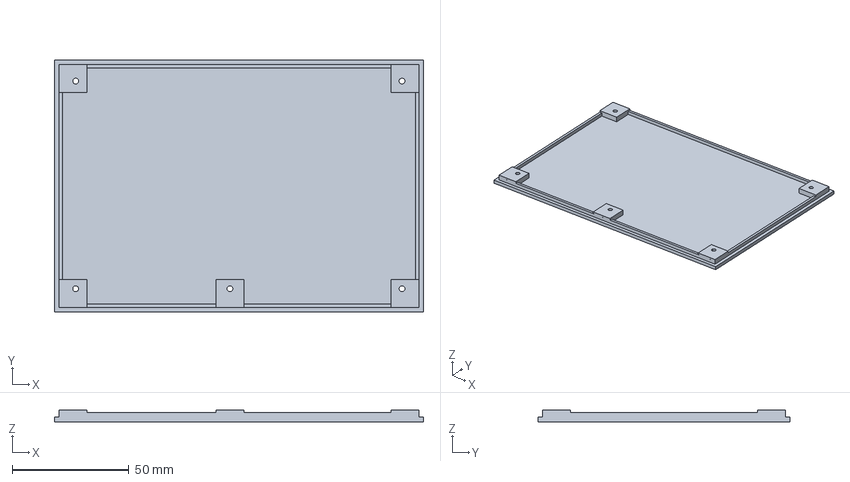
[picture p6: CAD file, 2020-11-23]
hard/CPU/v0/housing/housing base/cura-slicer/PLsi v0 - Housing Base rev E - CURA.3mf
158.0 x 108.0 x 5.00 mm

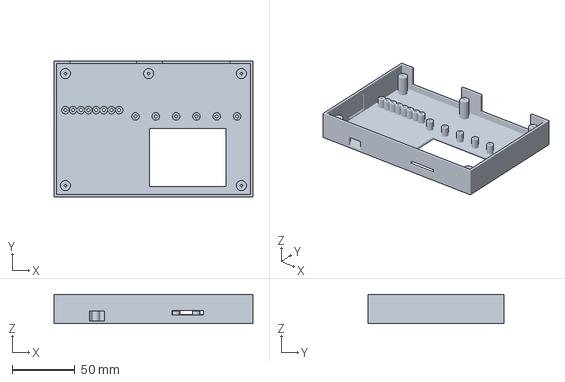
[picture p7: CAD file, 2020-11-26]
hard/CPU/v0/housing/housing cover/cura-slicer/PLsi v0 - Housing Cover rev E - CURA.3mf
158.0 x 108.0 x 23.3 mm

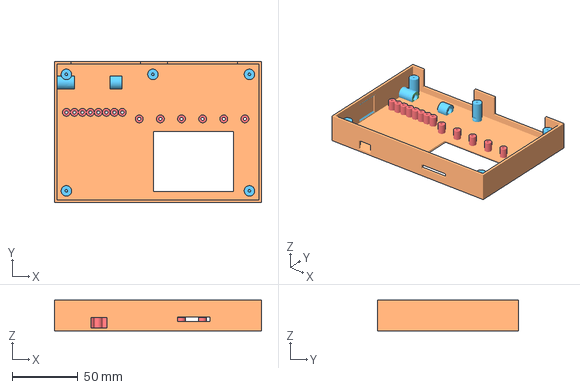
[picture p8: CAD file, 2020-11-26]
hard/CPU/v0/housing/housing cover/PLsi v0 - Housing Cover rev F.3mf
158.0 x 108.0 x 23.3 mm

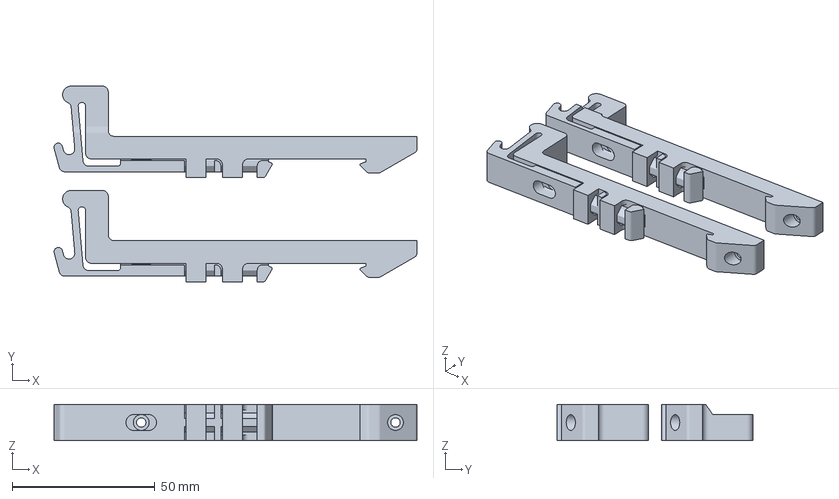
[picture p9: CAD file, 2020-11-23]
hard/CPU/v0/housing/housing din rail/cura-slicer/PLsi v0 - Housing Din Rail rev A - CURA.3mf
127.1 x 68.5 x 12.7 mm

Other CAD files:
hard/CPU/v0/housing/housing base/PLsi v0 - Housing Base rev E.3mf
hard/CPU/v0/housing/housing din rail/PLsi v0 - Housing Din Rail rev A.3mf
hard/CPU/v0/housing/housing base/cura-slicer/PLsi v0 - Housing Base rev E.stl
hard/CPU/v0/housing/housing cover/cura-slicer/PLsi v0 - Housing Cover rev E.stl
hard/CPU/v0/housing/housing cover/PLsi v0 - Housing Cover rev E.3mf
hard/CPU/v0/housing/housing din rail/cura-slicer/PLsi v0 - Housing Din Rail rev A.stl
hard/CPU/v0/housing/housing cover/cura-slicer/PLsi v0 - Housing Cover rev F - CURA.3mf

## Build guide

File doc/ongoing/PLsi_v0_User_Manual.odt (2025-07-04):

PLsi v0

User Manual

Project page:

https://github.com/ElPercha/PLsi

# Purpose of this document

This manual provides information about wiring, configuration and programming of PLsi v0 CPU unit.

For building and assembly instructions, initial firmware download and hardware validation, refer to “PLsi v0 Hardware Manual”.

Please, create an issue in the PLsi repository (https://github.com/ElPercha/PLsi/issues) if you see that this manual is not clear enough or has opportunities to improve.

MANUAL UNDER CONSTRUCTION

## Document information

Manual Name: PLsi_v0_User_Manual

Revision: MANUAL UNDER CONSTRUCTION

Date: July 4, 2025

## Revision history

Revision | Date | Description | Latest Firmware
A | July 4, 2025 | First Revision | V0.00.03

# License

The complete PLsi Project is under MIT license.

MIT License

Copyright (c) 2019 Lucas Prieto

Permission is hereby granted, free of charge, to any person obtaining a copy

of this software and associated documentation files (the "Software"), to deal

in the Software without restriction, including without limitation the rights

to use, copy, modify, merge, publish, distribute, sublicense, and/or sell

copies of the Software, and to permit persons to whom the Software is

furnished to do so, subject to the following conditions:

The above copyright notice and this permission notice shall be included in all

copies or substantial portions of the Software.

THE SOFTWARE IS PROVIDED "AS IS", WITHOUT WARRANTY OF ANY KIND, EXPRESS OR

IMPLIED, INCLUDING BUT NOT LIMITED TO THE WARRANTIES OF MERCHANTABILITY,

FITNESS FOR A PARTICULAR PURPOSE AND NONINFRINGEMENT. IN NO EVENT SHALL THE

AUTHORS OR COPYRIGHT HOLDERS BE LIABLE FOR ANY CLAIM, DAMAGES OR OTHER

LIABILITY, WHETHER IN AN ACTION OF CONTRACT, TORT OR OTHERWISE, ARISING FROM,

OUT OF OR IN CONNECTION WITH THE SOFTWARE OR THE USE OR OTHER DEALINGS IN THE

SOFTWARE.

# Safety Guidelines

All applicable local and national codes that regulate the installation and operation of your equipment shall be followed in order to minimize the risk of potential safety issues.

PLsi is not fault-tolerant and must not be used to control equipment in hazardous environments where the failure of the system could lead to death, people injury, or severe environmental damage. Refers to the Disclaimer notice for more information.

This manual contains 3 levels of hints:

WARNING: Death, serious harm to health or equipment damage can result if the stated measures are not followed !

CAUTION: Harm to health or equipment damage can result if the stated measures are not followed

TIP: Important information that requires your special attention

# Table of Contents

# 1. Introduction

The objective of the PLsi project is to create a PLC & HMI with the following main characteristics:

- To not require external systems such us Laptops or Cellphones to be programmed
- To be used on Classroom for educational purposes, IoT applications or industrial low risk applications
- Software and Hardware with Industrial performance and features
- Open Source and Open Hardware
- Focus on Low Cost

The PLsi v0 Hardware main characteristics:

- ESP32 Processor - Dual Core @240MHZ
- Wi-Fi connectivity
- 2.8" Touchscreen Display
- Removable Terminal blocks
- USB 5Vdc main power supply
- I2C port for hardwired expansions
- SD Card slot

The PLsi v0 board is designed to support different input output configurations. This manual will cover the 2 main suggested configurations:

1. Digital version:
  - 8 digital inputs (5 to 26VDC)
  - 6 relay outputs (10A max per PLsi, external fuse required)
2. Analog version:
  - 6 digital inputs (5 to 26VDC)
  - 4 relay outputs (10A max per PLsi, external fuse required)
  - 2 Analog Inputs (0-5V)
  - 2 Analog Outputs (0-5V)

This definition will modify the I/O addressing and wiring.

Refer to the “Hardware manual” for more information about the 2 main configuration and electrical details.

## 1.1 Project documentation

The PLsi project is hosted on GitHub:

https://github.com/ElPercha/PLsi

The tree structure is divided in 3 main folders:

1. doc: Contains project documentation and auxiliary tools
2. firm: Contains the Firmware, it is designed using PlatformIO + Visual Studio
3. hard: Contains the Hardware documentation, mainly:
  - Circuit schematic
  - Component list
  - Board fabrication details
  - 3D Printed housing fabrication details
  - 3D Printed Din Rail support fabrication details

The most updated information is located on the master branch (link provided above), but it also might contain nightly builds of the firmware, hardware or any document. For this reason, it is recommended to use the “releases”, they are a more trustworthy information source.

Each release contains a snapshot of the full project site by the moment of his creation, plus the required binaries to flash the ESP32 module.

By the time this document was created, the latest revision available is the “v0.00.03”.

## 1.2 Prerequisites

There are not special prerequisites to became a PLsi user and programmer.

This manual will introduce and explain the configuration options and programming instructions from scratch, providing step by step instructions and examples for the most common functions.

# 2. Hardware Specifications

The following sections provide in advance information about the connection and PLsi v0

Main characteristics:

• Easy to build, no SMD components. DIY!

• ESP32 Processor

◦ Dual Core @240MHZ

◦ Wi-Fi connectivity

• 2.8" 320x240 Touchscreen Display

• 8 Hardware Inputs 5-24VDC Isolated with status led

• 6 Hardware Relay Outputs with status led. Max 10A, external fuse required

• Different combinations of Digital and Analog I/O using the same board

◦ Analog I/O range: 0-5V

• Removable Terminal blocks

• USB 5Vdc main power supply

• I2C port for hardwired expansions

• SD Card slot

• 3D printed housing model including DIN rail mounting bracket

# 3. Software Specifications

Aclarar que se bien se van a revisar los detalles en los capitulos posteriores, aca se presentan las caracteristicas principales

Aclarar que se refiere el manual al Firmware v0.00.03

Main Software Characteristics:

- PLC Ladder Logic Instruction set:
  - 35 instructions
  - Boolean instructions full set
  - Timers and Counters full set
  - Comparisons full set
  - 16 bit math functions
- PLC Memory Areas:
  - 2000 Marks (M)
  - 200 Counters (C)
  - 300 Timers (T)
  - 10000 Registers 16bits (D)
- PLC Program size:
  - Up to 400 networks of 6x5 cells (12K boolean instructions)
  - Up to 4 PLC programs stored on internal memory (max. 400 networks each)
- PLC Program Editor
  - Online Edition (with PLC running)
  - Row, Column and Network Editor
  - Network Navigation
- PLC performance and control
  - Scan time of 2.3ms for 2000 Boolean instructions
  - Processor Core 1 runs Ladder Logic exclusively
  - RUN/STOP with user confirmation
- Display functions:
  - PLC Programming and debugging
  - PLsi Configuration
  - HMI
    - "Fix" version implemented (User cannot edit memory areas nor texts)
    - Screen 1: 8 Switches M500 to M507
    - Screen 2: 8 Buttons M510 to M517
    - Screen 3: 8 User Input Values D500 to D507
    - Screen 4: Local I/O visualization
    - Screen 5: 8 Indicators M520 to M527
- Communications:
  - Wi-Fi configuration. Only DHCP
  - SSID scanning functionality
- Firmware update via Web Page
- Analog Inputs and Outputs
  - Selectable via Configuration page

# 4. General Concepts

The objective of the PLsi project is to create a PLC & HMI with the following main characteristics:

- To not require external systems such us Laptops or Cellphones to be programmed
- To be used on Classroom for educational purposes, IoT applications or industrial low risk applications
- Software and Hardware with Industrial performance and features

## 4.1 Ladder Logic

Generalidades de ladder Logic, algun buen resumen corto de internet, tal vez con graficos

### 4.1.1 Networks Organization

Esquema de organizacion de las 400 networks / celdas de la network

Tambien se pueden nombrar los 4 programas disponibles, como un primer nivel

### 4.1.1 Network Execution

Esquema de ejecucion en zig zag de la network, como se barre

Aclarar que las cosas se ejecutan cuando estan conectadas a la barra de poder de la izquierda

### 4.1.1 Online Edition

Comentar las dos posibilidades de edicion y sobre todo los riesgos aparejados con la edicion online

## 4.2 Memory Areas

Explicar los distintos datatypes, rangos y usos comunes. Hay que armar una tabla como la que tiene el excel

## 4.3 Instructions Overview

Tabla con resumen de todas las instrucciones disponibles y breve explicacion de cada una (descripcion en l amisma tabla)

### 4.3.1 LL984 extension

Comentar las instrucciones avanzadas ladder 984, cuales son

## 4.4 Keyboards

The

### 4.4.1 Alphanumeric Keyboard

Explicar las 4 paginas y como cambiar entre ellas

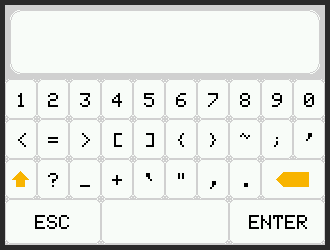
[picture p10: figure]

### 4.4.2 Numeric Keyboard

The following diagram shows the main connections required for your PLsi v0 Digital version.

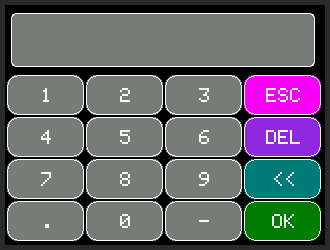
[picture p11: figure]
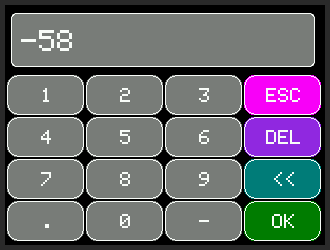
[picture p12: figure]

Ejemplo, introducir: (-) + 5 + 8 + OK

# 5. Getting started

The following sections provide in advance information about the connection and PLsi v0

## 5.1 Power Up

The following sections provide in advance information about the connection and PLsi v0

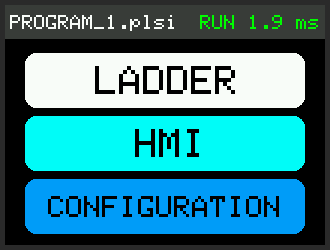
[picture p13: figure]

## 5.2 Switching CPU states RUN / STOP

The following sections provide in advance information about the connection and PLsi v0

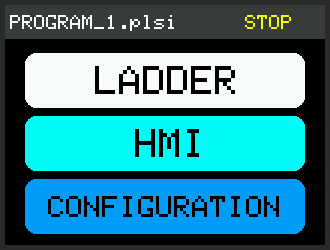
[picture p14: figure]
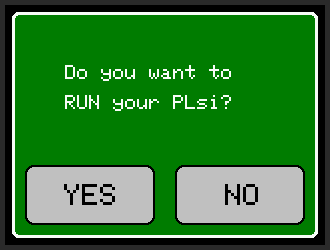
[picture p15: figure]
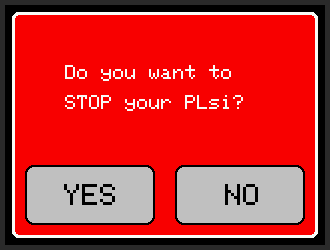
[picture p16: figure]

cuando un Error esta presente se ve el mensaje de ERR en el campo Status:

Tambien se puede editar desde el Ladder Logic section:

Explicar el concepto de ‘barra de poder’ de la izquiera, que cambia de color indicando run/stop

De igual manera se puede ver el error.

Pulsar en el campo status “ERR” para limpiar el error siempre que sea posible

## 5.3 Demo program

Explicar que el firmware recien cargado trae en el Slot de programa 1, un programa demo para probar las funciones basicas

### 5.3.1 Turning Q0 on

Explicar los pasos basicos para encender el output 0 (basicamente es pulsar el boton M500 en el HMI)

### 5.3.2 Turning I0 on

Mostrar cableado basico para encender un input

# 6. Wiring

Mostrar todos los conectores y su funcion en un diagrama con flechas y las siguientes referencias:

1. USB Main Power supply
2. I2C
3. SD Card
4. Display
5. 5V auxilares
6. Bornera Inputs
7. Bornera Outputs

## 6.1 Digital Version wiring

tomar info del otro manual

Aclarar Fusible externo max current 10A

Mostrar esquema de tierras (Todo IO esta aislado)

## 6.2 Analog Version wiring

tomar info del otro manual

Aclarar Fusible externo max current 10A

Mostrar esquema de tierras (Analog IO no esta aislado)

# 7. Configuration

The following sections provide in advance information about the connection and PLsi v0

## 7.1 PLC

The

## 7.2 HMI

The

## 7.3 I/O

The

## 7.4 Network

The

### 7.4.1 Wi-Fi

Primariamente usada para permitir bajar el Firmware

### 7.4.2 Modbus TCP

Not yet available

### 7.4.3 Web Server

Not yet available

### 7.4.4 S7 Connection

Not yet available

## 7.5 System

Firmware download

# 8. Programming

Resumen de capitulo programacion

Overview de los campos en esta pantalla ppal de ladder logic:

Home

Flechas << >>

Network, para tipear el numero al que quiero ir

RUN/STOP para cambiar el modo

EDIT, siguiente capitulo.

## 8.1 Edition Mode

Pulsar EDIT para acceder al modo edicion, explicar que se puede cancelar con el icono ROJO (arriba a la derecha o aceptar con la palomita verde

Seleccionar una celda para editar:

### 8.1.1 Navigation and Main Functions

Explicar la navegacion

- Flechas << >> (Se cambia de pantalla)
- Campo informativo Network + ROW + COLUMN
- DELETE
- CANCEL
- ACCEPT

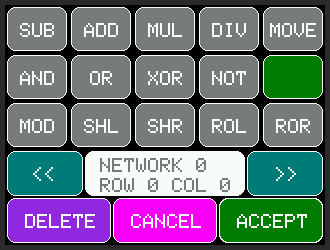
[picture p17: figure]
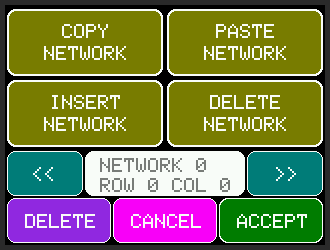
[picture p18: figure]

### 8.1.2 Row Editor

Explicar como se Copia, Pega, Inserta o Borra

### 8.1.3 Column Editor

Explicar como se Copia, Pega, Inserta o Borra

### 8.1.4 Network Editor

Explicar como se Copia, Pega, Inserta o Borra

## 8.2 Instructions

Explicacion de los disstintos grupos de instrucciones

- Booleans (NO / NC / RE / FE / C / L / U)
- Connectors (INV / CON / BAR / MOVE)
- Timers (TON / TOFF / TP)
- Counters (CTU / CTD)
- Math (SUB / ADD / MUL / DIV / MOD)
- Logical (AND / OR / XOR / NOT)
- Bits Shifting (SHL / SHR / ROL / ROR)
- Comparison (EQ / GT / GE / LT / LE / NE)

### 8.2.1 NO – Normal Open Contact

Explicar normal open contact (se pueden buscar ejemplos de internet)

Explicar la siguiente la secuencia de edicion

Aclarar los distintos tipos de memoria que se pueden y mostrar como se ve el rango permitido con cada seleccion

- I – Digital Inputs – Range: I0 - I199
- M – Marks (general use flags) Range M0 – M 1999
- Q – Digital Outputs – Range: Q0 - Q199
- Td – Timer Done Flag – Range: Td0 - Td299
- Tr – Timer running Flag – Range: Tr0 - Tr299
- Cd – Counter Done Flag – Range: Cd0 - Cd199
- Cr – Counter running Flag – Range: Cr0 - Cr199

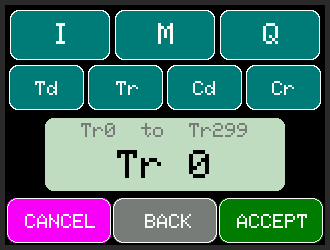
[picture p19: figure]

### 8.2.2 NC – Normal Closed Contact

Explicar normal open contact (se pueden buscar ejemplos de internet)

### 8.2.3 RE – Rise Edge Contact

Explicar la instruccion

### 8.2.4 FE – Fall Edge Contact

Explicar la instruccion

### 8.2.5 C – Coil

Explicar la instruccion

En esta instruccion, se deben usar solamente M o Q por ser naturalmente salidas del sistema, evitar usar otro tipo de tipos d ememoria.

### 8.2.6 L – Latch Coil

Explicar la instruccion

En esta instruccion, se deben usar solamente M o Q por ser naturalmente salidas del sistema, evitar usar otro tipo de tipos d ememoria.

### 8.2.7 U – Unlatch Coil

Explicar la instruccion

En esta instruccion, se deben usar solamente M o Q por ser naturalmente salidas del sistema, evitar usar otro tipo de tipos d ememoria.

### 8.2.8 BAR – Vertical Bar

Explicar el connector

### 8.2.9 CON – Horizontal Connection

Explicar el conector

### 8.2.10 INV – Horizontal Connection with Inversion

Explicar el conector

### 8.2.11 TON – Timer On

Explicar la instruccion con un diagrama de tiempos (se pueden buscar ejemplos en internet)

Aclarar que esta instruccion ocupa 2 celdas

Explicar que se pueden cambiar los 3 valores tocando en cada campo

1 – El numero del timer

2 – El valor hasta donde va a contar

3 – la Base de tiempo

Valores de Base de Tiempo Posibles:

- Minutes
- Seconds
- Millseconds
- 0.01 Seconds
- 0.1 Seconds

Explicar las patitas de salida

La de arriba se enciende cuando el timer termino

En el ejemplo esta esta asociada al flag Td8

La de abajo mientras esta contando

En el ejemplo esta esta asociada al flag Tr8

Ton Reset (Not turned ON)

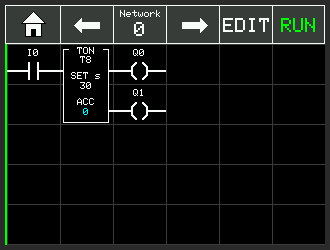
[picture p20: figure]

TON Running:

TON Done:

### 8.2.12 TOFF – Timer Off

Explicar la instruccion con un diagrama de tiempos (se pueden buscar ejemplos en internet)

Aclarar que esta instruccion ocupa 2 celdas

Explicar que se pueden cambiar los 3 valores tocando en cada campo

1 – El numero del timer

2 – El valor hasta donde va a contar

3 – la Base de tiempo

Valores de Base de Tiempo Posibles:

- Minutes
- Seconds
- Millseconds
- 0.01 Seconds
- 0.1 Seconds

Toff reset

TOFF input active, copia la salida de arriba:

Cuando se apaga la input que lo mantiene activo, inicia su cuenta:

Refleja el estado Running en la salida de abajo mientras mantiene la salida de arriba activa

Muy usado para antirebotes

Cuando termina de contar:

### 8.2.13 TP – Timer Pulse

Explicar la instruccion con un diagrama de tiempos (se pueden buscar ejemplos en internet)

Aclarar que esta instruccion ocupa 2 celdas

Explicar que se pueden cambiar los 3 valores tocando en cada campo

1 – El numero del timer

2 – El valor hasta donde va a contar

3 – la Base de tiempo

Valores de Base de Tiempo Posibles:

- Minutes
- Seconds
- Millseconds
- 0.01 Seconds
- 0.1 Seconds

Timer not activated:

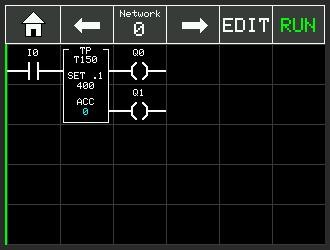
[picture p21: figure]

Timer activated

Timer done status:

En este ejemplo se aprecia como la salida inferior se activa y permanece en este estado aun cuando el timer sigue contando, esto es especuialmente util cuando se quieren hacer enclavamiendos y antirebotes

### 8.2.14 CTU – Counter Up

Explicar la instruccion con un diagrama de tiempos (se pueden buscar ejemplos en internet)

Explicar los campos editables, son los dos de arriba

- Counter number
- Count targer
- El campo de abjo que dice counts no es editable.

Esta instruccion ocupa 2 celdas

Tiene dos patitas de entrada

La de arriba cuenta

En el ejemplo I0

La de abajo es resets

En el ejemplo I1

Tiene 2 salidas

La de arriba se activa cuando llega a la cuenta

La de abajo se activa cuando esta “contando” pero no llego a la cuenta siempre y cuando la entrada de “contar” este actiba

Cuando se desactiva la entrada de conteo el flag de salida infe

Cuando llega a la cuenta se enciende la salida superior, indicando que la cuenta alcanzo su target

### 8.2.15 CTD – Counter Down

Explicar la instruccion con un diagrama de tiempos (se pueden buscar ejemplos en internet)

Explicar los campos editables, son los dos de arriba

- Counter number
- Count targer
- El campo de abjo que dice counts no es editable.

Mismas patitas de entrada y salida que el otro contador

Explicarlas.

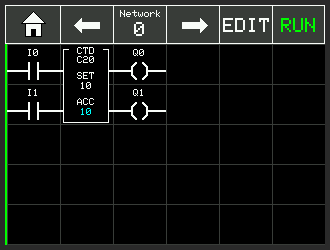
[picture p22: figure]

### 8.2.16 SUB – Arithmetic Subtraction

Explicar la instruccion

A – B = C

A es el de arriba

B es el del medio C es la salida

Explicar los posibles datatypes

- D – Registros de 16 Bits
- T – Valor de un Timer
- C – Valor de un contador
- IW Valor de una entrada Analogica
- K – Valor Constante
- QW Valor de una salida analogica

En la salida, no se pueden usar IW ni K porque son seniales de solo lectura

Ejemplo:

Tomar el registro D500

Restarle el valor -56

Colocar el resultado en el registro D501

Resultado 56

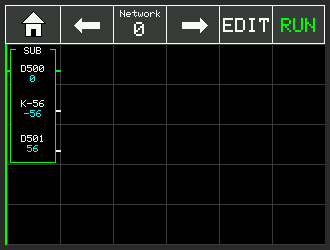
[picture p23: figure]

Aclarar que ocupa 3 celdas

Aclarar que tiene una patita de entrada y 3 de salida que se activan de acuerdo al resultado, es decir, se puede usar para restar y comparar al mismo tiempo

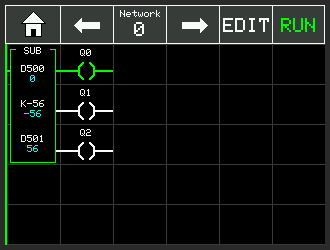
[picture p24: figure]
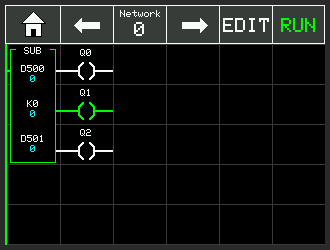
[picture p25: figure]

### 8.2.17 ADD – Arithmetic Addition

Explicar la instruccion

A + B = C

A es el de arriba

B es el del medio C es la salida

Explicar los posibles datatypes

- D – Registros de 16 Bits
- T – Valor de un Timer
- C – Valor de un contador
- IW Valor de una entrada Analogica
- K – Valor Constante
- QW Valor de una salida analogica

En la salida, no se pueden usar IW ni K porque son seniales de solo lectura

Acclarar que ocupa 3 celdas

Aclarar que solo tiene una patita de entrada y una de salida que siempre se activa cuando se activa la de la entrada

### 8.2.18 MUL – Arithmetic Multiplication

Explicar la instruccion

A * B = C

A es el de arriba

B es el del medio C es la salida

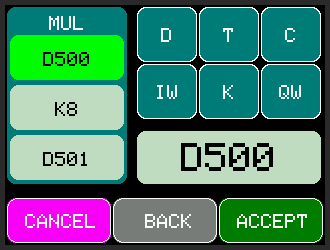
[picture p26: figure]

Explicar los posibles datatypes

- D – Registros de 16 Bits
- T – Valor de un Timer
- C – Valor de un contador
- IW Valor de una entrada Analogica
- K – Valor Constante
- QW Valor de una salida analogica

En la salida, no se pueden usar IW ni K porque son seniales de solo lectura

En este caso se uso el HMI para demostrar esta operacion:

### 8.2.19 DIV – Arithmetic Division

Explicar la instruccion

A / B = C

A es el de arriba

B es el del medio C es la salida

Explicar los posibles datatypes

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

En la salida, no se pueden usar IW ni K porque son seniales de solo lectura

Aclarar que la patita de arriba se enciende siempre que sea una operacion valida, por ejemplo:

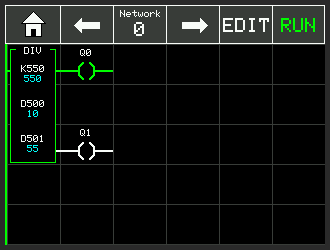
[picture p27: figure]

Y la salida de abajo, se enciende ante un error, indicando que el resultado no es valido. En este caso cuando se divide por 0

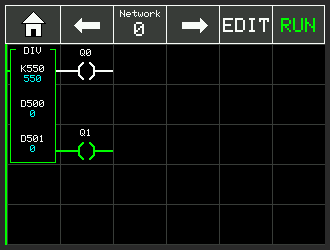
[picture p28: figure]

### 8.2.20 MOVE – Register Transfer

Explicar la instruccion

B = A

A es el de arriba

B es el salida (Abajo)

Instruccion ocupa 2 celdas

### 8.2.21 AND – Bitwise AND

Explicar la instruccion

Es una AND logica

Explicar un poco el sistema HEXADECIMAL

Ejemplo

Operador 1: 0xF

Operador 2: 0xA

Resultado: 0xA

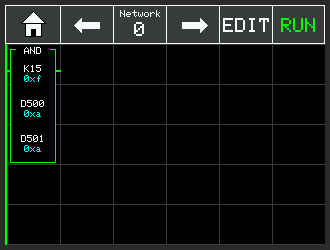
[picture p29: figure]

### 8.2.22 OR – Bitwise OR

Explicar la instruccion

Es una OR logica

Ejemplo:

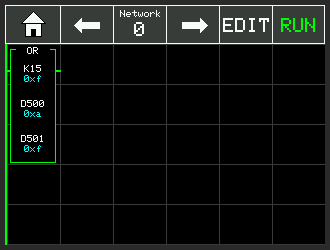
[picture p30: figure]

### 8.2.23 XOR – Bitwise XOR

Explicar la instruccion

Es una XOR logica

Ejemplo:

### 8.2.24 NOT – Bitwise NOT

Explicar la instruccion

Es una NOT logica (Niega el input y lo pone en el resultado a nivel bit)

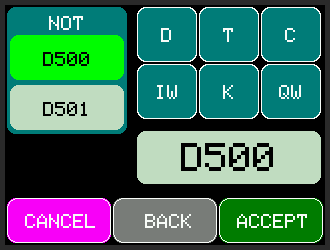
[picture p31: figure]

Ejemplo:

### 8.2.25 MOD – Division Module

Explicar la instruccion

Es el modulo (Resto) de una division

Ejemplo:

### 8.2.25 SHL – Bit Shifting Left

Explicar la instruccion

Ejemplo:

### 8.2.26 SHR – Bit Shifting Right

Explicar la instruccion

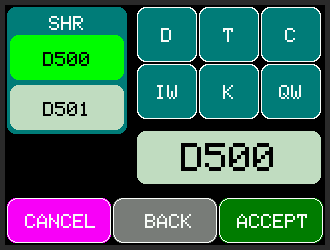
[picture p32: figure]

Example:

Explicar como se entiende en Hexa y en Binario para este tipo de instrucciones:

### 8.2.28 ROL – Bit Rotation Left

Explicar la instruccion

Rota todos los bits y el de la izquierda, en este caso lo inserta en el primer bit de la derecha

(El deborde del bit mas significativo, lo inserta en el menos significativo)

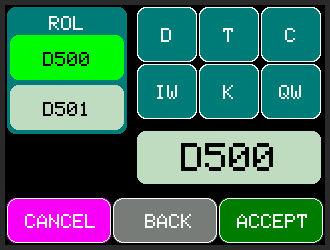
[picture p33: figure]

Ejemplo:

### 8.2.29 ROR – Bit Rotation Right

Explicar la instruccion

Example:

### 8.2.30 EQ – Equal to

Explicar la instruccion

Buscar en el Zip todos los screenshots para las 35 instrucciones que puedan faltar

### 8.2.31 GT – Greater than

Explicar la instruccion

Buscar en el Zip todos los screenshots para las 35 instrucciones que puedan faltar

### 8.2.32 GE – Greater than or Equal to

Explicar la instruccion

Buscar en el Zip todos los screenshots para las 35 instrucciones que puedan faltar

### 8.2.33 LT – Less than

Explicar la instruccion

Buscar en el Zip todos los screenshots para las 35 instrucciones que puedan faltar

### 8.2.34 LE – Less than or Equal to

Explicar la instruccion

Buscar en el Zip todos los screenshots para las 35 instrucciones que puedan faltar

### 8.2.35 NE – Not Equal to

Explicar la instruccion

Buscar en el Zip todos los screenshots para las 35 instrucciones que puedan faltar

## 8.3 Edition Errors

### 8.3.1 Not enough Rows to fit this instruction

Insertar imagenes con el error y un ejemplo de cuando sucederia

## 8.4 Examples

Explicacion de los disstintos grupos de instrucciones

Start Stop con L y U

Start Stop con retencion

Start Stop con retencion y se agrega estado de guardamotor

Timer On – Senial Diente de sierra

Timer On Senial ON/OFF con periodo de 0.5 s ( Se usa un sSUB para comparar o un GT)

# 9. HMI

The following sections provide in advance information about the connection and PLsi v0

| Using HMI | Navigation
| | Screens navigation

Insetar todas las pantallas caputadas y explicar las funciones y las areas de memoria asignadas by default (por ahora no se pueden editar)

PLsi v0 User Manual Page 77 of 77

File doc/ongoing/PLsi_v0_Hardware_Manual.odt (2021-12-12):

PLsi v0

Hardware Manual

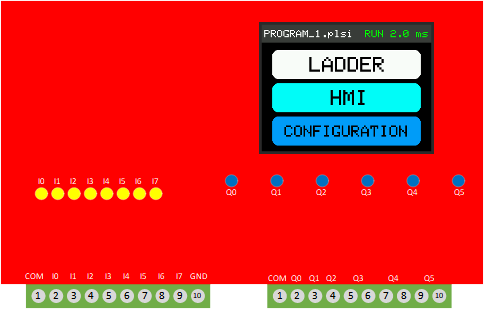
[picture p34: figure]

Project page:

https://github.com/ElPercha/PLsi

# Purpose of this document

This PLsi manual provides you with information to build a PLsi v0 unit, it comprises the board assembly, firmware download and a series of tests to validate the main functionalities. For wiring, configuration and programming information use the “PLsi v0 User Manual” instead.

Please, create an issue in the PLsi repository (https://github.com/ElPercha/PLsi/issues) if you see that this manual is not clear enough or has opportunities to improve.

# Document information

Manual Name: PLsi_v0_Hardware_Manual

Revision: A

Date: January 20, 2021

## Revision history

Revision | Date | Description
A | March 20, 2021 | First Revision

# License

The complete PLsi Project is under GPL v3.0 license.

This includes Hardware, Software, Documentation and all related contributions:

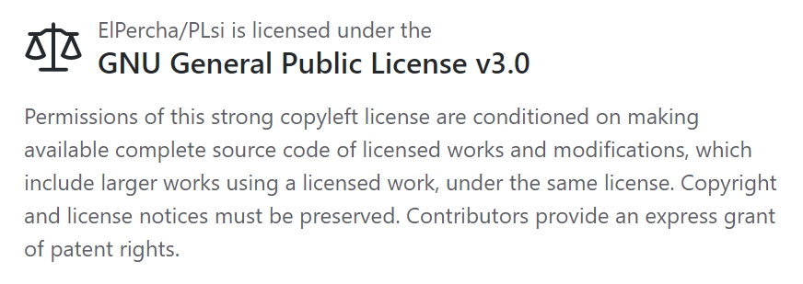
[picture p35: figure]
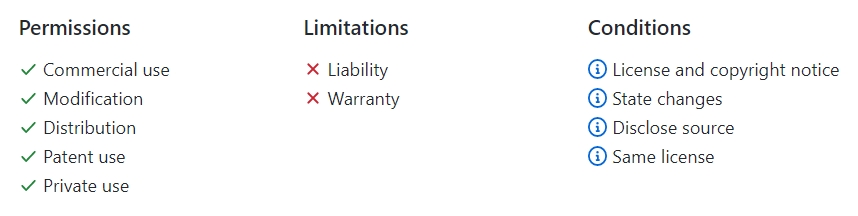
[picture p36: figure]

A full copy of the License is included on the Master branch of the project for reference:

https://github.com/ElPercha/PLsi/blob/master/LICENSE

Original copy with useful FAQ:

https://www.gnu.org/licenses/gpl-3.0.html

# Disclaimer

Copyright (c) 2019 Prieto Lucas. All rights reserved.

This file is part of the PLsi project.

PLsi is free software and hardware: you can redistribute it and/or modify

it under the terms of the GNU General Public License as published by

the Free Software Foundation, either version 3 of the License, or

(at your option) any later version.

PLsi is distributed in the hope that it will be useful,

but WITHOUT ANY WARRANTY; without even the implied warranty of

MERCHANTABILITY or FITNESS FOR A PARTICULAR PURPOSE. See the

GNU General Public License for more details.

You should have received a copy of the GNU General Public License

along with this program. If not, see <https://www.gnu.org/licenses/>.

# Safety Guidelines

All applicable local and national codes that regulate the installation and operation of your equipment shall be followed in order to minimize the risk of potential safety issues.

PLsi is not fault-tolerant and must not be used to control equipment in hazardous environments where the failure of the system could lead to death, people injury, or severe environmental damage. Refers to the Disclaimer notice for more information.

This manual contains 3 levels of hints:

WARNING: Death, serious harm to health or equipment damage can result if the stated measures are not followed !

CAUTION: Harm to health or equipment damage can result if the stated measures are not followed

TIP: Important information that requires your special attention

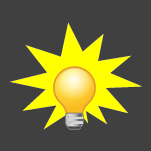
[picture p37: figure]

# 1. Introduction

The objective of the PLsi project is to create a PLC & HMI with the following main characteristics:

- To not require external systems such us Laptops or Cellphones to be programmed
- To be used on Classroom for educational purposes, IOT applications or industrial low risk applications
- Software and Hardware with Industrial performance and features
- Open Source and Open Hardware
- Focus on Low Cost

The hardware version 0 of PLsi system is designed to be cheap and easy to build. It does not have SMD components, what makes the building process easy, fast and feasible using basic tools. The components selection was oriented to use easy to get and cheap elements.

The PLsi v0 is mainly composed by:

- Main board
- ESP32 module
- TFT 2.8” SPI Display module with touchscreen
- Terminal blocks and common electronic components

The PLsi v0 board is designed to support different input output configurations. This manual will cover the 2 main suggested configurations. For that reason, before to start, you have to select which version are you going to build, these are the 2 main options:

1. Digital version:
  - 8 digital inputs (5 to 26VDC)
  - 6 relay outputs (10A max per PLsi, external fuse required)
2. Analog version:
  - 6 digital inputs (5 to 26VDC)
  - 4 relay outputs (10A max per PLsi, external fuse required)
  - 2 Analog Inputs (0-5V)
  - 2 Analog Outputs (0-5V)

This definition will modify your component list. The details of which component is required on each version is covered on the following chapters.

## 1.1 Project documentation

The PLsi project is hosted on GitHub:

https://github.com/ElPercha/PLsi

The tree structure is divided in 3 main folders:

1. doc: Contains project documentation and auxiliary tools
2. firm: Contains the Firmware, it is designed using PlatformIO + Visual Studio
3. hard: Contains the Hardware documentation, mainly:
  - Circuit schematic
  - Component list
  - Board fabrication details
  - 3D Printed housing fabrication details
  - 3D Printed Din Rail support fabrication details

The most updated information is located on the master branch (link provided above), but it also might contain nightly builds of the firmware, hardware or any document. For this reason, it is recommended to use the “releases”, they are a more trustworthy information source.

Each release contains a snapshot of the full project site by the moment of his creation, plus the required binaries to flash the ESP32 module.

By the time this document was created, the latest revision available is the “v0.00.03”.

It is recommended to use the latest available release to build your PLsi unit.

https://github.com/ElPercha/PLsi/releases

The details on how to use the binary files to flash your PLsi are going to be covered during the next chapters.

## 1.2 Minimum system

The easiest way to build a PLsi v0 is using the board designed for it, but for PLsi CPU testing purposes (with no Inputs Outputs) a limited system can be easily built.

It consist of:

- ESP32 WROOM module
  - 38 pins version
  - They typically have yellow pin terminals
  - For test purposes you can use another ESP32 module as long as it has dual core, but the described model is required if you use the PLsi v0 board.
- 2.8” 320x240 SPI TFT Display – LcdWiki info (http://www.lcdwiki.com/2.8inch_SPI_Module_ILI9341_SKU:MSP2807)
  - Driver ILI 9341
  - Touchscreen driver XPT2046 (https://github.com/Bodmer/TFT_eSPI/issues/849)
  - For test purposes you can use another display, as long as it has the same interface, resolution and drivers, but the described model is required if you use the PLsi v0 board.
- 9 Jumper cables for the ESP32 ← → Display connections.
- Micro USB cable and adapter with 1A capacity (recommended 2A)
  - This fed the ESP32 module and it is the main incoming supply voltage of the PLsi v0

Required ESP32 ← → Display connections for minimal system:

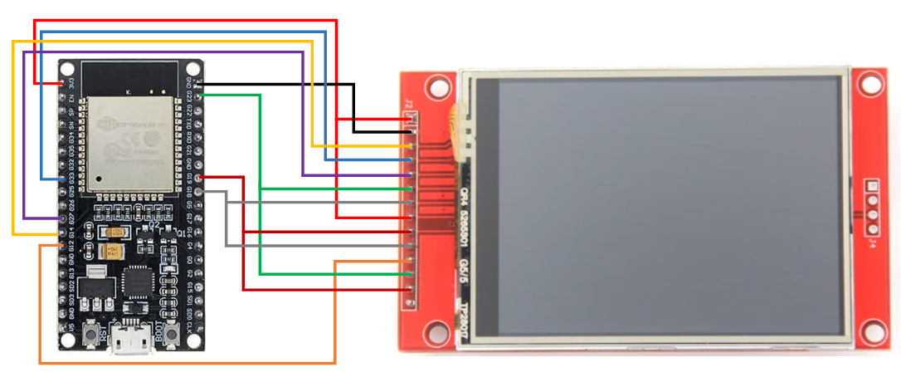
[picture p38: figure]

  In the above sketch the minimal connections are shown.
  The only pending activity to complete the test will be the Firmware download to ESP32.
  It is detailed in Firmware Download chapter.

Required ESP32 Module

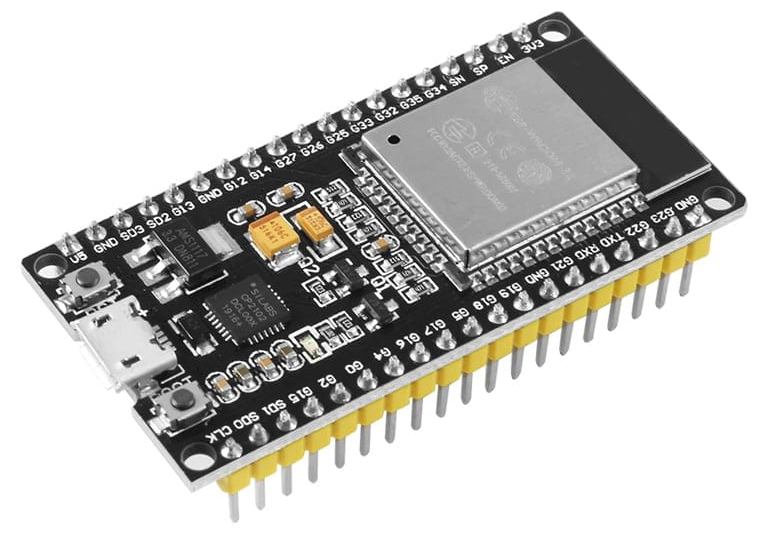
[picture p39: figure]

Dimensions:

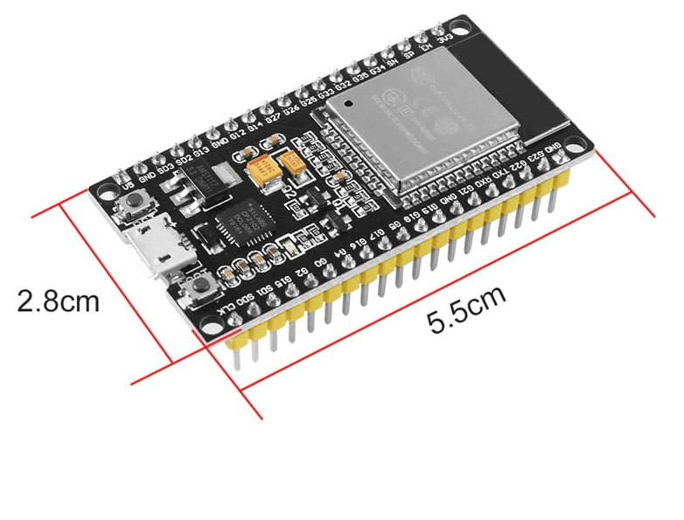
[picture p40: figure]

Required display:

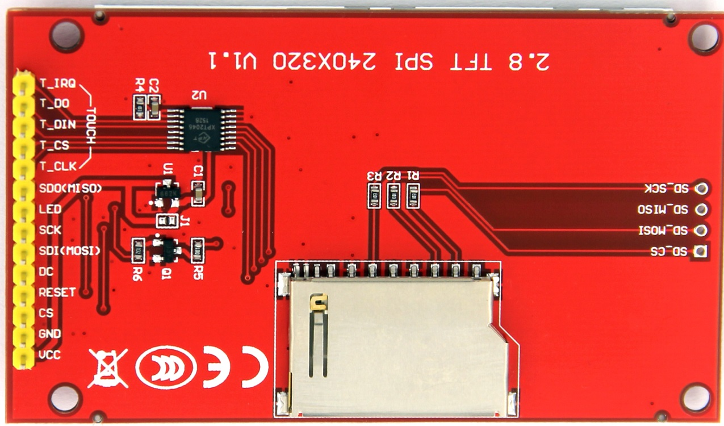
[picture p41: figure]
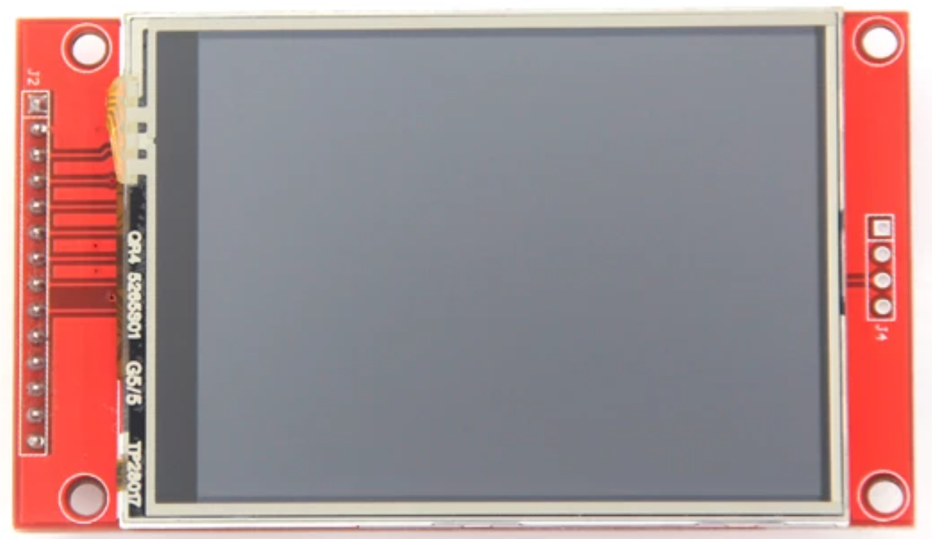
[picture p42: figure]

## 1.3 Drawing

# 2. Board Assembly

The recommended way to build your PLsi is using the board designed for it.

All the required files to build the board are provided In the hard (hardware) folder. Each PLsi hardware version has his own folder.

  PLsi v0 board main folder:

https://github.com/ElPercha/PLsi/tree/master/hard/v0/board

Folder content:

- Gerber Files
- EasyEDA source
- Altium source (it is a beta export option of the EasyEDA platform, not tested)
- Schematic
- BOM
  The EasyEDA project is also public and for this reason you can directly clone the project, download or open the files from here:
    https://oshwlab.com/funnyautomation/PLsi_0

The Boards used to prototype the PLsi v0 were ordered to:

https://jlcpcb.com/

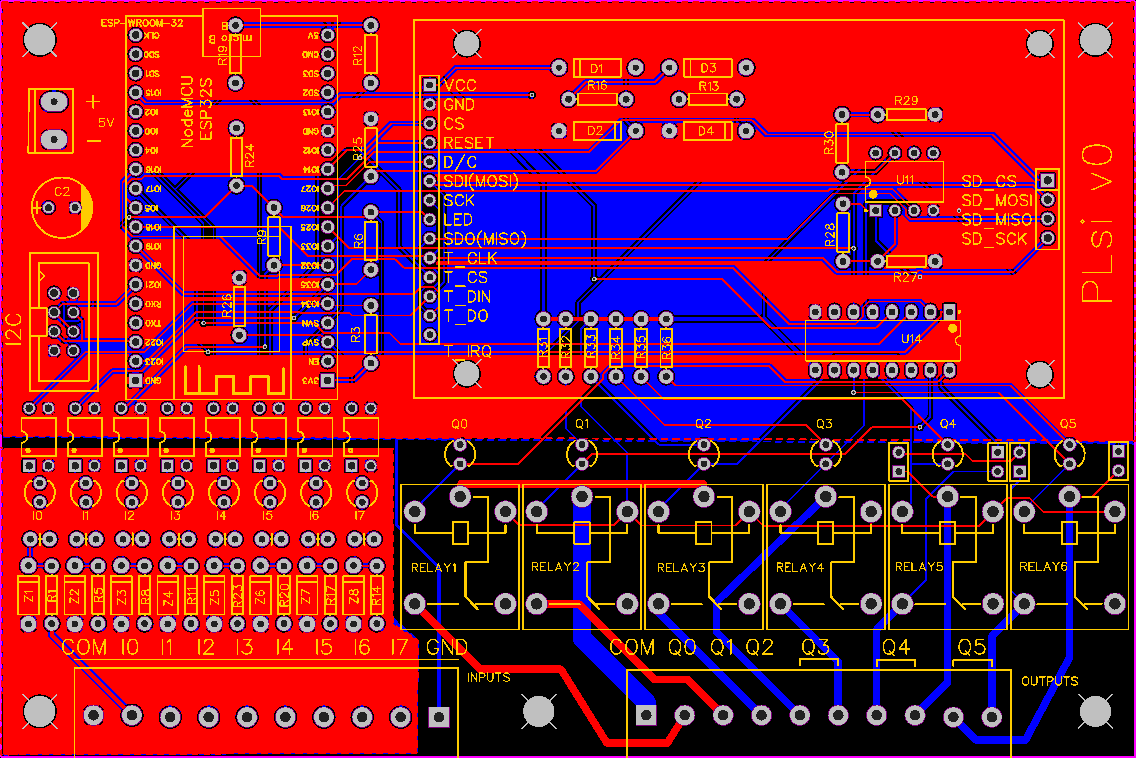
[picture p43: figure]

## 2.2 Digital version

The hardware v0 digital version will have:

- 8 digital inputs (5 to 26VDC)
- 6 relay outputs (10A max per PLsi, external fuse required)

The component list with links to AliExpress options can be found here:

https://github.com/ElPercha/PLsi/tree/master/hard/v0-CPU

### 2.2.1 Component list

The following table has the list of components required to build your PLsi v0 digital:

Item | Designator | Description | Quantity
1 | U1 | NodeMCU_ESP32S | 1
2 | U2 | Touch Screen Display | 1
3 | U14 | ULN2003N | 1
4 | INPUTS, OUTPUTS | 5.08 x 10 Terminal block | 2
5 | U2 – SD Card conenction pins | Dupont 2.54mm Male strip | 4 pins
6 | U1 and U2 - Optional socket | Dupont 2.54mm Female strip | 2 x 40 pins
7 | 5V | Dupont 3 pins male | 3 pins
8 | P4 | HDR-IDC-2.54-2X4P | 1
9 | C2 | Capacitor 1000uF 9V | 1
10 | OPTO1, OPTO2, OPTO3, OPTO4, OPTO5, OPTO6, OPTO7, OPTO8 | Optocupler PC817 | 8
11 | Z1, Z2, Z3, Z4, Z5, Z6, Z7, Z8 | Diode 5v1 – Zenner 1w | 8
12 | I0, I1, I2, I3, I4, I5, I6, I7 | Leds 3mm Color 1 | 8
13 | Q0, Q1, Q2, Q3, Q4, Q5 | Leds 3mm Color 2 | 6
14 | R3, R6, R9, R12, R13, R16, R19, R24 | Resistor 10k | 8
15 | R1, R5, R8, R11, R14, R17, R20, R23 | Resistor 1K x 1/2W | 8
16 | R2, R4, R7, R10, R15, R18, R21, R22 | Resistor 510 ohms | 8
17 | R31, R32, R33, R34, R35, R36 | Resistor 330 ohms | 6
18 | RELAY1, RELAY2, RELAY3, RELAY4, RELAY5, RELAY6 | SRD-05VDC-SL-C | 6

The latest version of the BOM (Bill of Materials) file, with more information, is available on:

https://github.com/ElPercha/PLsi/tree/master/hard/v0-CPU/board/bom

### 2.2.2 Assembly

There is no special considerations on the bulding process. This section will recommended a step by step secuence to facilitate the assembly process:

## 2.3 Analog version

PLsi is not fault-tolerant and must not be used to control equipment in hazardous environments where the failure of the system could lead to death, people injury, or severe environmental damage. Refers to the Disclaimer notice for more information.

ANALOG resolution. Lineatization issue

### 2.3.1 Component list

PLsi is not fault-tolerant and must not be used to control equipment in hazardous environments

Item | Designator | Description | Quantity
1 | U1 | NodeMCU_ESP32S | 1
2 | U2 | Touch Screen Display | 1
3 | U14 | ULN2003N | 1
4 | INPUTS, OUTPUTS | 5.08 x 10 Terminal block | 2
5 | U2 – SD Card conenction pins | Dupont 2.54mm Male strip | 4 pins
6 | U1 and U2 - Optional socket | Dupont 2.54mm Female strip | 2 x 40 pins
7 | 5V | Dupont 3 pins male | 3 pins
8 | P4 | HDR-IDC-2.54-2X4P | 1
9 | C2 | Capacitor 1000uF 9V | 1
10 | OPTO1, OPTO2, OPTO3, OPTO4, OPTO5, OPTO6 | Optocupler PC817 | 6
11 | Z1, Z2, Z3, Z4, Z5, Z6 | Diode 5v1 – Zenner 1w | 6
12 | I0, I1, I2, I3, I4, I5 | Leds 3mm Color 1 | 6
13 | Q0, Q1, Q2, Q3 | Leds 3mm Color 2 | 4
14 | R3, R6, R9, R12, R19, R24 | Resistor 10k | 6
15 | R1, R5, R8, R11, R20, R23 | Resistor 1K x 1/2W | 6
16 | R2, R4, R7, R10, R21, R22 | Resistor 510 ohms | 6
17 | R31, R32, R33, R34 | Resistor 330 ohms | 4
18 | RELAY1, RELAY2, RELAY3, RELAY4 | SRD-05VDC-SL-C | 4
19 | D1, D2, D3, D4 | Diode 1N4148 | 4
20 | R25, R26, R37, R38, R39, R40 | Resistor 10k 1% | 6
21 | R27,R29 | Resistor 5k1 | 2
22 | R28,R30 | Resistor 3k3 | 2
23 | U11 | TLV2462CP | 1

where the failure of the system could lead to death, people injury, or severe environmental damage. Refers to the Disclaimer notice for more information.

### 2.3.2 Assembly

PLsi is not fault-tolerant and must not be used to control equipment in hazardous environments where the failure of the system could lead to death, people injury, or severe environmental damage. Refers to the Disclaimer notice for more information.

# 3. Firmware Download

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

## 3.1 Required files

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

## 3.2 Espressif download tool

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

## 3.3 Compile the source

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

### 3.3.1 PLsi customization

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

# 4. Hardware Validation

This step is optional but recommended…………..

## 4.1 Digital Inputs validation

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

## 4.2 Digital Outputs validation

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

## 4.3 Analog Inputs validation

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

## 4.4 Analog Outputs validation

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

DIY: Como construir:
| listado de componentes
| | minimo para probar esp32 y display
| explicacion del circuito
| | Detalles placa i2c etc
| | mencionar analogicos
| construir placa
| | montaje paso a paso?
| bajar firmware con esp32 tool
| | 0x1000 - bootloader_dio_40m.bin
| | 0x8000 - partitions.bin
| | 0xe000 - boot_app0.bin
| | 0x10000 - firmware.bin
| | https://www.espressif.com/en/products/socs/esp32/resources
| | la herramienta esta incluida pero si queres la ultima version proveer link
| | en la carpeta de la gherramienta esta el manual once you unzip
| o compilar con platformio no mucho detalle
| | si tienen problemas que avisen

PLsi v0 Hardware Manual Page 23 of 23

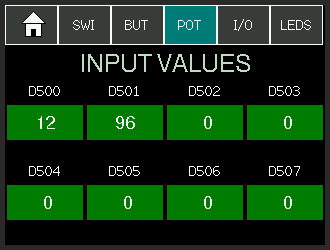
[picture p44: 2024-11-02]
doc/ongoing/Auxiliars/UserManualScreenShoots/1 - Ladder/4 - Instructions/18 - MUL/MUL 2.png

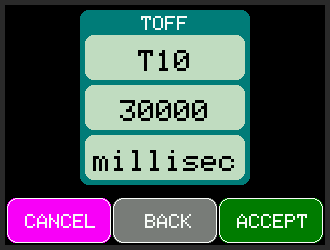
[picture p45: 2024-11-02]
doc/ongoing/Auxiliars/UserManualScreenShoots/1 - Ladder/4 - Instructions/12 - TOFF/TOFF.png

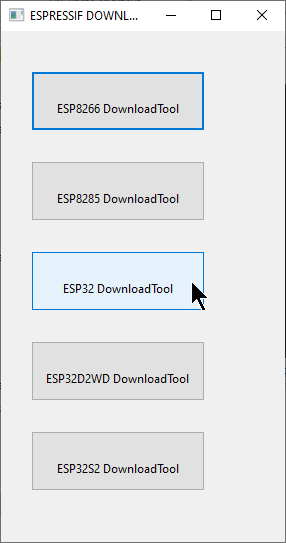
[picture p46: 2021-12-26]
doc/ongoing/Auxiliars/pictures for manuals/2.png

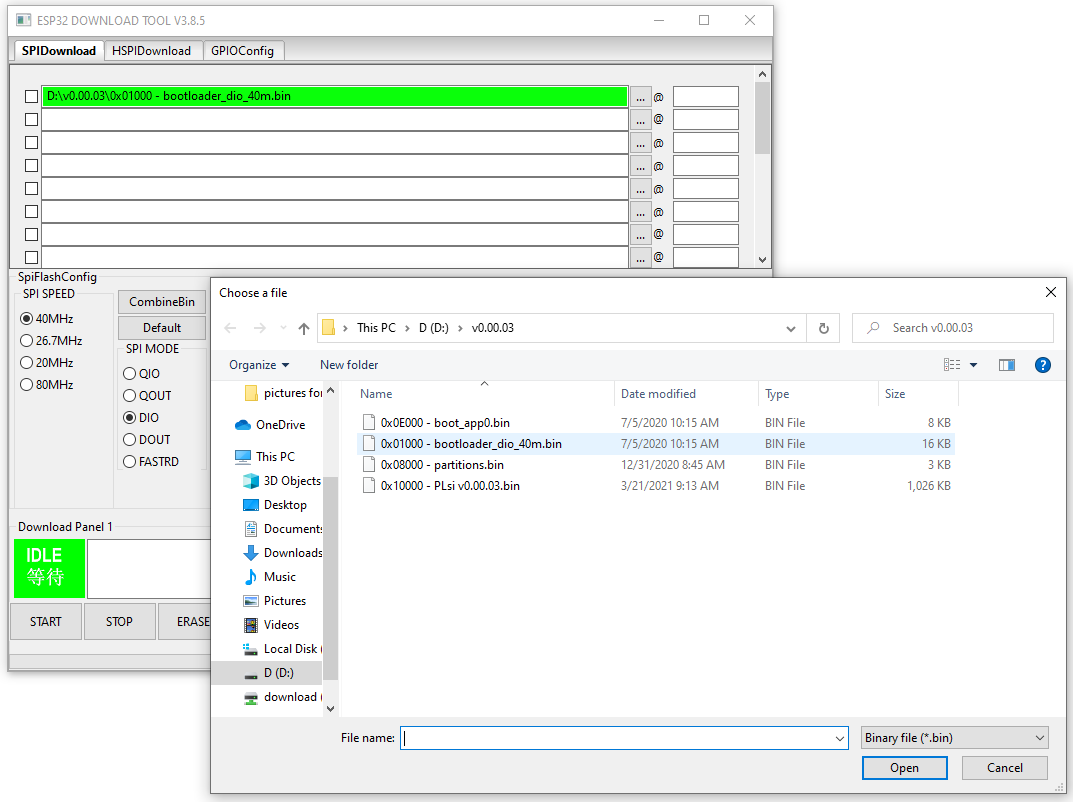
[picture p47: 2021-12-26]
doc/ongoing/Auxiliars/pictures for manuals/download1.PNG

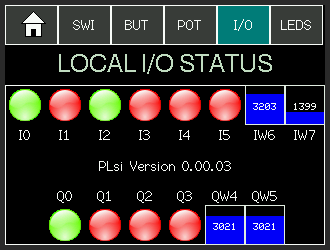
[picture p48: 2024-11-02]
doc/ongoing/Auxiliars/UserManualScreenShoots/2 - HMI/8.png

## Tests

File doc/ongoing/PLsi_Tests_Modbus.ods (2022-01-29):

Modbus TCP Server Memory Allocation consumption
Operation | Estimated Memory allocated in Bytes |  |  |  |  | Estimated Memory allocated per unit
 | General | x10 | x100 | x1000 | x10000 | Per unit | Per unit | Per unit | Per unit
mb.server(); |  | 728 | 732
mb.addIsts(0, 0, x) – 1xxxx |  | 212 | 1552 |  |  | 21.2 | 15.52 | 0 | 0
mb.addIreg(0, 0, x) – 3xxxx |  | 192 | 1536 |  |  | 19.2 | 15.36 | 0 | 0
mb.addHreg(0, 0, x) – 4xxxx |  | 140 | 1152 |  |  | 14 | 11.52 | 0 | 0
mb.addCoil(0, 0, x) – 0xxxx |  | 384 | 1536 |  |  | 38.4 | 15.36 | 0 | 0

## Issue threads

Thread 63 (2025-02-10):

New ladder library

hiperiondev, 2025-02-10:
Buenas ....tanto tiempo!
Despues de millones de cosas que han pasado por mi vida vuelvo sobre este proyecto por necesidades personales.

He convertido toda la lógica en una librería portable, y totalmente configurable.
La implementación es: https://github.com/hiperiondev/ladderlib

El acceso al hardware asi como las logicas opcionales en cada ciclo de ejecucion se pueden definir de forma externa, lo cual permite utilizarla en cualquier micro, asi como adaptar a las necesidades de cada uno.

No modifiqué la estructura básica del scan, pero si como se resuelve internamente. Simplifiqué muchisimas cosas y bajé al minimo el consumo de memoria.

Agregué dos utilidades opcionales: Por un lado la impresion del programa en una forma "ascii amistosa" y un interprete de crontab para generar eventos externos (en mi caso muy necesario porque lo voy a usar para varias cosas de automatizacion de mi casa).

Ahora voy a crear un minimo de documentacion y la implementacion para ESP32 (ahora está el port dummy que funciona como demo en Linux)

Saludos,

hiperiondev, 2025-02-10:
Vi que no está correctamente implementado el tipo Real, posiblemente resuelva eso antes

Closed 2025-02-11.

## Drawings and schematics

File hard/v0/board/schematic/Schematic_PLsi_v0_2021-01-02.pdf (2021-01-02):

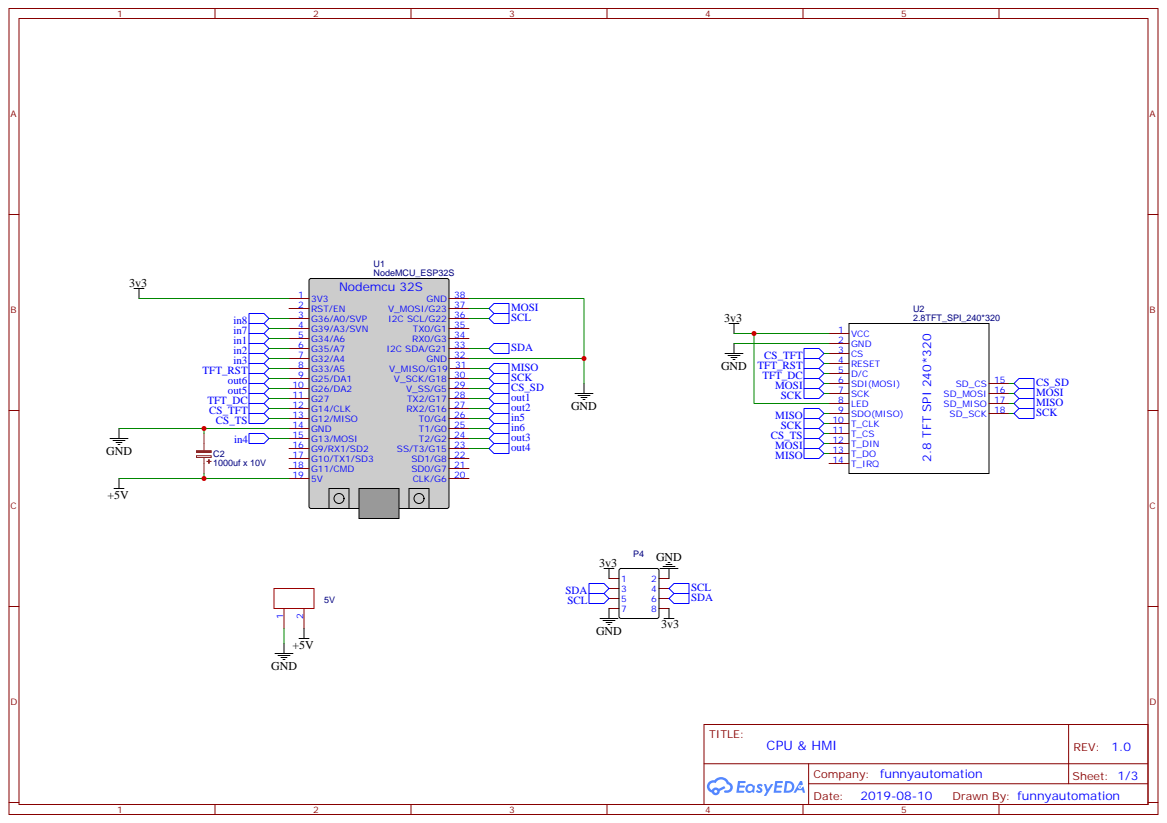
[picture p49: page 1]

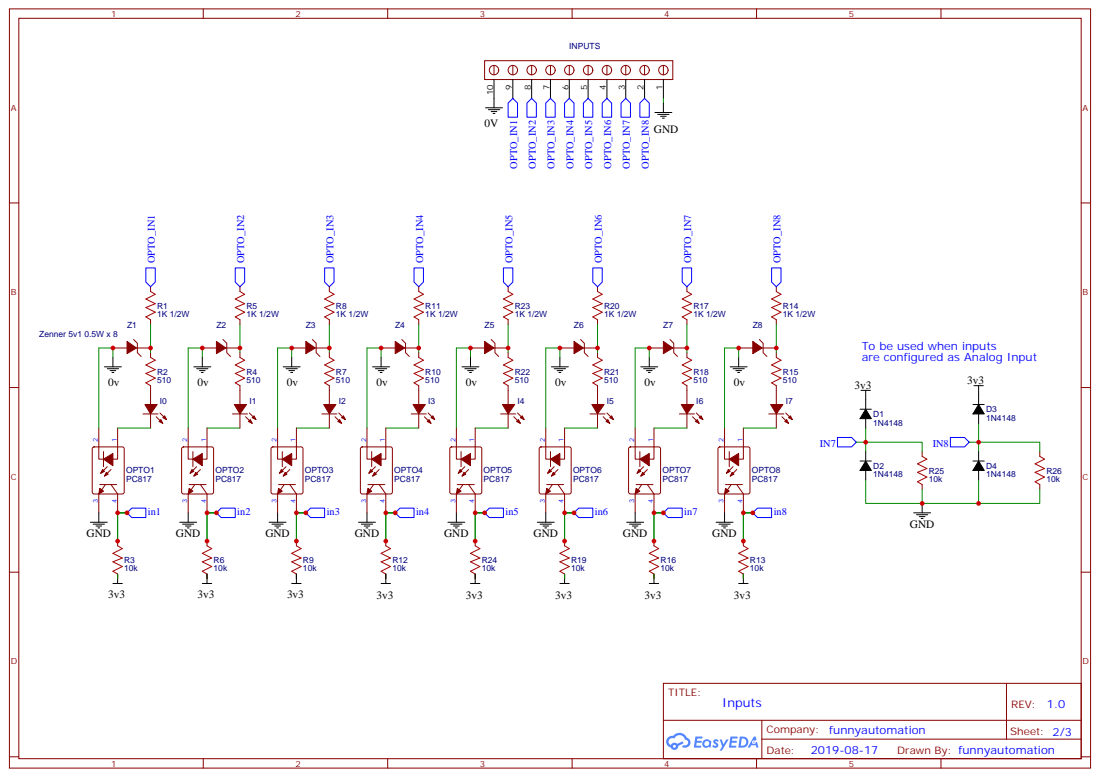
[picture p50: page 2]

To be used when inputs
are configured as Analog Input

## To be used when Outputs are configured as Analog Outputs

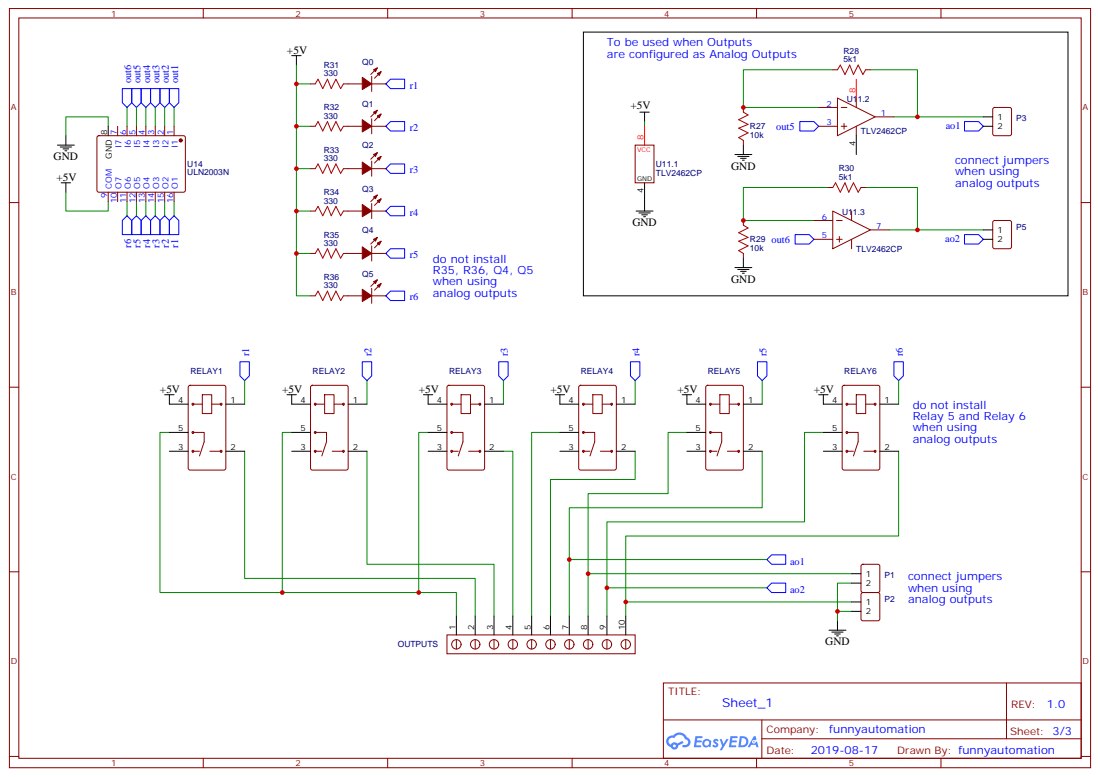
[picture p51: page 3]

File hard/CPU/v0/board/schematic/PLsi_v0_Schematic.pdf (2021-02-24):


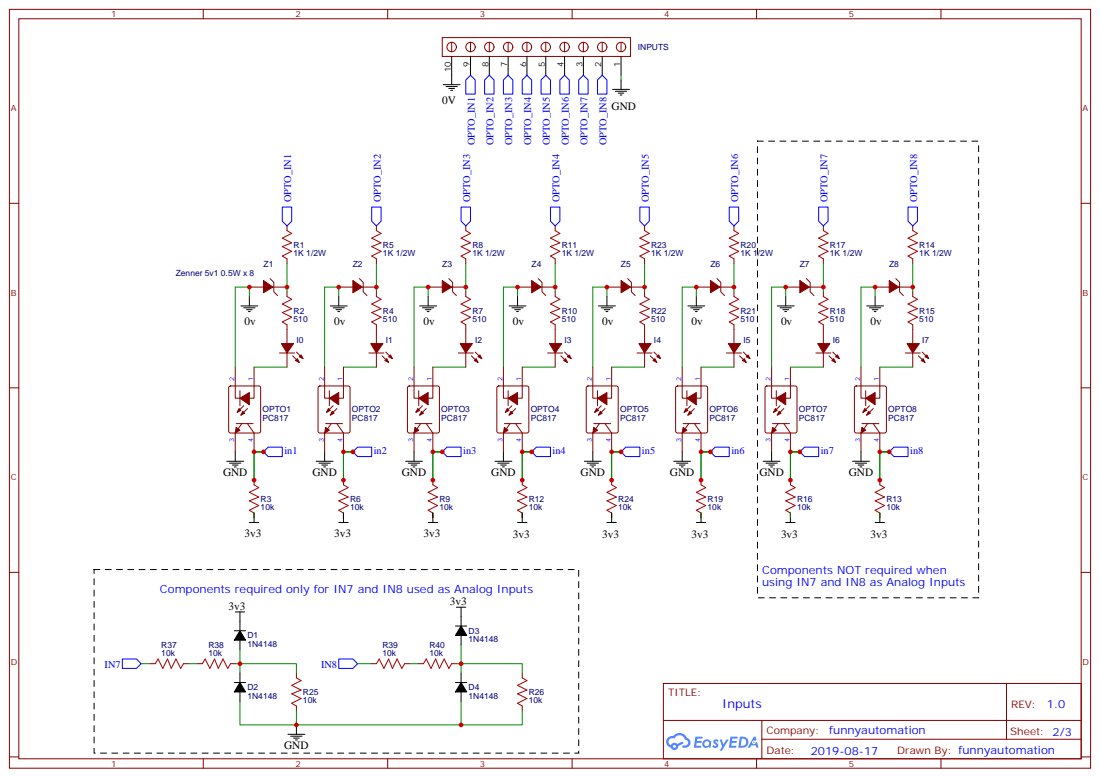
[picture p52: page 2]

Components NOT required when
using IN7 and IN8 as Analog Inputs

Components required only for IN7 and IN8 used as Analog Inputs

## To be used when Outputs are configured as Analog Outputs

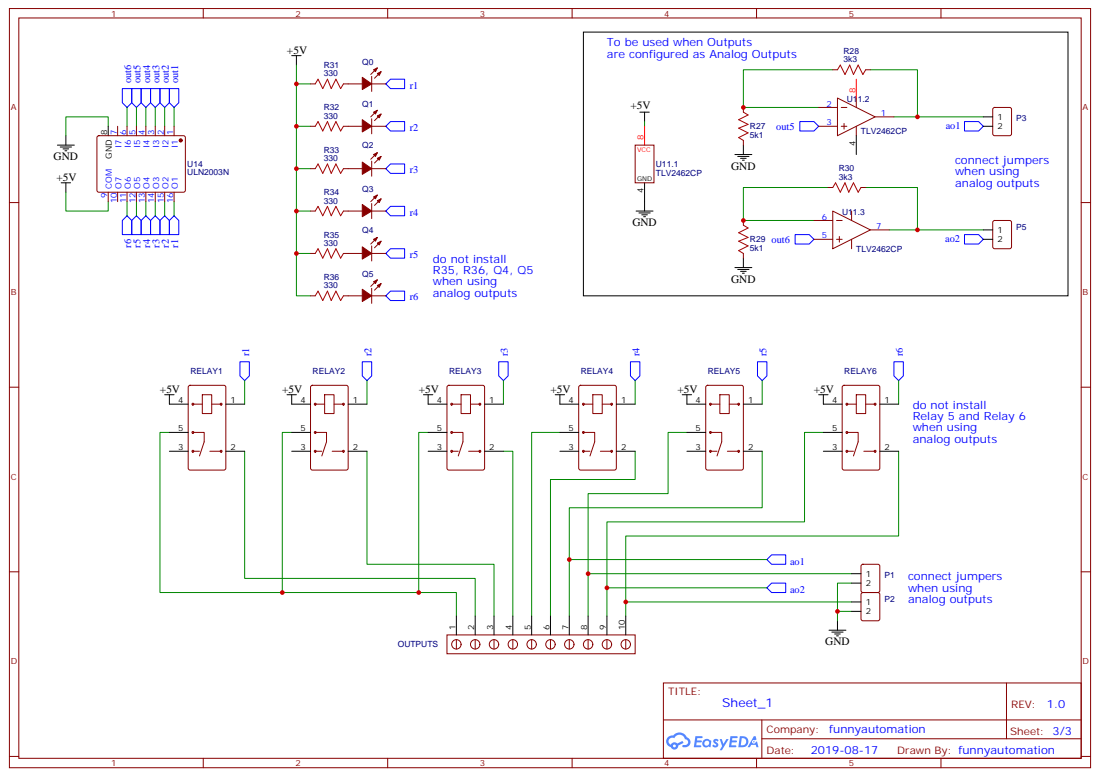
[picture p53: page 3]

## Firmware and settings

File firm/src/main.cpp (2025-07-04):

// Copyright (c) 2019 Lucas Prieto
// Licensed under the MIT License. See LICENSE file in the project root for full license information.

#include <globals.h>
#include <main.h>

//--------------------------------------------------------------------------------
// Standard setup
//--------------------------------------------------------------------------------

void setup() {

  //--------------------------------------------------------------------------------
  // Serial Console initialization
  //--------------------------------------------------------------------------------

  Serial.begin(BAUD_RATE); 

  //--------------------------------------------------------------------------------
  // RTOS tasks configuration and setup
  //--------------------------------------------------------------------------------
  
  xTaskCreatePinnedToCore(
    TaskHMI
    ,  "HMI display"
    ,  4096   // Stack size up to 113000
    ,  NULL
    ,  2      // Priority 3=highest 0=lowest
    ,  NULL 
    ,  0);    // Processor Core 

  xTaskCreatePinnedToCore(
    TaskDisk
    ,  "Disk management"
    ,  4096
    ,  NULL
    ,  0
    ,  NULL 
    ,  0);

  xTaskCreatePinnedToCore(
    TaskWiFi
    ,  "WiFi communications"
    ,  4096 
    ,  NULL
    ,  1
    ,  NULL 
    ,  0);

  xTaskCreatePinnedToCore( 
    TaskLadder
    ,  "Ladder Logic"
    ,  80000  // Networks structure size is 76000 leaving 4K free
    ,  NULL
    ,  3
    ,  NULL 
    ,  1);    // Ladders Logic runs on Core 1
}

//--------------------------------------------------------------------------------
// Standard loop not used
//--------------------------------------------------------------------------------

void loop() {
    delay(1000);
}

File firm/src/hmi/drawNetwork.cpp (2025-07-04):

// Copyright (c) 2019 Lucas Prieto
// Licensed under the MIT License. See LICENSE file in the project root for full license information.

#include <globals.h>
#include <TFT_eSPI.h>
#include <hmi.h>

//--------------------------------------------------------------------------------
// Ladder Logic Network drawing functions
//--------------------------------------------------------------------------------

void drawNetwork (void){
  uint16_t code;

  typedef void (*DrawLadderLogic) (int n, int c, int r, int f);
  DrawLadderLogic drawLadder [] =
  {
    drawNop,    
    drawConn,   
    drawNeg,
    drawNo,
    drawNc,
    drawRe,
    drawFe,
    drawCoil,
    drawCoilL,
    drawCoilU,
    drawTon,
    drawToff,
    drawTp,
    drawCtu,
    drawCtd,
    drawMove,
    drawSub,
    drawAdd,
    drawMul,
    drawDiv,
    drawMod,
    drawShl,
    drawShr,
    drawRol,
    drawRor,
    drawAnd,
    drawOr,
    drawXor,
    drawNot,
    drawEq,
    drawGt,
    drawGe,
    drawLt,
    drawLe,
    drawNe
  };

  // Update Power Bar ststus
  drawPowerBar();
  
  // Draw / Update Ladder instructions  
  for (int c=0; c<NET_COLUMNS; c++){
    for (int r=0; r<NET_ROWS; r++){
      code = onlineNetwork.Cells[r][c].Code;

      if (code & CELL_USED_MASK){
        if ((code & CELL_CODE_MASK) >= FIRST_INVALID_CODE){ 
          Serial.println("TASK HMI - CORE 0 - INSTRUCTION CODE INVALID: ");
          Serial.print("   - Network: ");
          Serial.println(showingNetwork);
          Serial.print("   - Row: ");
          Serial.println(r);
          Serial.print("   - Column: ");
          Serial.println(c);
          Serial.print("   - Code: ");
          Serial.println(code);
        }
        code = 0;
      } 
      drawLadder[code](r, c, GetFlag(r, c), GetData(r, c));
    } 
  }
  // Draw / Update Ladder bars
  for (int c=0; c<NET_COLUMNS-1; c++){
    for (int r=0; r<NET_ROWS-1; r++){
      if (onlineNetwork.Bars[c] & FlagsMask[r]){
        if (NetworkFlagsOnline[c] & FlagsMask[r]){
          drawBar (r, c, COLOR_ON);   
        }
        else{
          drawBar (r, c, COLOR_OFF);   
        }
      }
    }
  }
}

int GetData (int r, int c){
  int returnData = 0;
  switch (onlineNetwork.Cells[r][c].Type) {
    case TypeM:
      returnData = int(M[onlineNetwork.Cells[r][c].Data]);
      break;
    case TypeQ:
      returnData = int(Q[onlineNetwork.Cells[r][c].Data]);
      break;
    case TypeI:
      returnData = int(I[onlineNetwork.Cells[r][c].Data]);
      break;
    case TypeCd:
      returnData = int(Cd[onlineNetwork.Cells[r][c].Data]);
      break;
    case TypeCr:
      returnData = int(Cr[onlineNetwork.Cells[r][c].Data]);
      break;
    case TypeTd:
      returnData = int(Td[onlineNetwork.Cells[r][c].Data]);
      break;
    case TypeTr:
      returnData = int(Tr[onlineNetwork.Cells[r][c].Data]);
      break;
    case TypeIW:
      returnData = int(IW[onlineNetwork.Cells[r][c].Data]);
      break;
    case TypeQW:
      returnData = int(QW[onlineNetwork.Cells[r][c].Data]);
      break;
    case TypeC:
      returnData = int(C[onlineNetwork.Cells[r][c].Data]);
      break;
    case TypeD:
      returnData = int(D[onlineNetwork.Cells[r][c].Data]);
      break;
    case TypeT:
      returnData = int(Timers[onlineNetwork.Cells[r][c].Data].ACC);
      break;
    case TypeK:
      returnData = int(onlineNetwork.Cells[r][c].Data);
      break;
//    case TypeR:
//      returnData = R[onlineNetwork.Cells[r][c].Data];
//      break;
    default:
      ;
    break;
  }
  return returnData;
}

int GetFlag (int r, int c){
  int returnData;

  if (c == 0){
    if (settings.ladder.PLCstate == RUNNING){returnData = 1;}
    else                    {returnData = 0;}
  }
  else{
    returnData = (NetworkFlagsOnline[c-1] & FlagsMask[r]);
  }
  return returnData;  
}

//--------------------------------------------------------------------------------
// Tags on Bits Instructions
//--------------------------------------------------------------------------------

void drawTagBit (int Row, int Column, int Color){
  int Xbase = Column * NET_COL_WIDTH + POWER_BAR_WIDTH; 
  int Ybase = Row * NET_ROW_HEIGTH + MENU_HEIGTH;
  
  String tagString = MnemonicsTypes[onlineNetwork.Cells[Row][Column].Type] + String(onlineNetwork.Cells[Row][Column].Data);

  tft.setCursor(((7-tagString.length())*3)+5+Xbase, 4+Ybase);
  tft.setTextColor(Color);
  tft.setTextSize(1);
  tft.print(tagString);
}

//--------------------------------------------------------------------------------
// Tags on Boxes
//--------------------------------------------------------------------------------

void drawBoxTag (int Row, int Column, int Color){
  int Xbase = Column * NET_COL_WIDTH + POWER_BAR_WIDTH; 
  int Ybase = Row * NET_ROW_HEIGTH + MENU_HEIGTH;
  
  String tagString1 = MnemonicsCodes[onlineNetwork.Cells[Row][Column].Code];

  tft.setTextColor(Color);
  tft.setTextSize(1);
  tft.setCursor(((7-tagString1.length())*3)+5+Xbase, 2+Ybase);
  tft.print(tagString1);
}

//--------------------------------------------------------------------------------
// Tags inside 2 cells Boxes
//--------------------------------------------------------------------------------

void drawBox2Tags (int Row, int Column, int Color){
  int Xbase = Column * NET_COL_WIDTH + POWER_BAR_WIDTH; 
  int Ybase = Row * NET_ROW_HEIGTH + MENU_HEIGTH;
  String tagString2;
  
  //First Row of tags
  String tagString1 = MnemonicsTypes[onlineNetwork.Cells[Row][Column].Type] + String(onlineNetwork.Cells[Row][Column].Data); 
  if(onlineNetwork.Cells[Row][Column].Code >= SHL && onlineNetwork.Cells[Row][Column].Code <= NOT){
    tagString2 =  "0x" + String(uint16_t(GetData(Row, Column)), HEX);    
  }
  else{
    tagString2 = String(GetData(Row, Column));
  }

  tft.setTextColor(Color);
  tft.setTextSize(1);
  tft.setCursor(((7-tagString1.length())*3)+5+Xbase, 20+Ybase);
  tft.print(tagString1);
  tft.setTextColor(COLOR_VALUES_ONLINE);
  tft.setCursor(((7-tagString2.length())*3)+5+Xbase, 30+Ybase);
  tft.fillRect(  5+Xbase, 30+Ybase, 43, 8, networkColorBack);
  tft.print(tagString2);

  //Second Row of tags
  tagString1 = MnemonicsTypes[onlineNetwork.Cells[Row+1][Column].Type] + String(onlineNetwork.Cells[Row+1][Column].Data); 
  if(onlineNetwork.Cells[Row][Column].Code >= SHL && onlineNetwork.Cells[Row][Column].Code <= NOT){
    tagString2 =  "0x" + String(uint16_t(GetData(Row+1, Column)), HEX);    
  }
  else{
    tagString2 = String(GetData(Row+1, Column));
  }

  tft.setTextColor(Color);
  tft.setCursor(((7-tagString1.length())*3)+5+Xbase, 50+Ybase);
  tft.print(tagString1);
  tft.setTextColor(COLOR_VALUES_ONLINE);
  tft.setCursor(((7-tagString2.length())*3)+5+Xbase, 60+Ybase);
  tft.fillRect(  5+Xbase, 60+Ybase, 43, 8, networkColorBack);
  tft.print(tagString2);
}

//--------------------------------------------------------------------------------
// Tags inside 3 cells Boxes
//--------------------------------------------------------------------------------
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

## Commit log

2019-11-17 test commit from VS
    [PLsi.ods]
2019-11-18 splitting Arduino program
2019-11-18 splitting Arduino files
2019-11-18 cleaning Arduino original project
2020-05-30 migrating Arduino program to PIO
    [PLsi.ods]
2020-05-31 hardware info uploaded
    [BOM_PLsi_0.xlsx]
2020-06-01 working on doc
    [PLsi.ods]
2020-06-07 Disk task organization
    [PLsi.xlsx]
2020-06-08 improve Wifi password management
    [PLsi.xlsx]
2020-07-22 WifiPassword now inside Settings structure
    [PLsi.xlsx]
2020-08-17 Ladder Editor SAVE/EDIT fix
    [hmi.h]
2020-08-23 save ts calibration to settings #15
2020-08-23 Save ts calibration to disk #14
2020-09-19 Cancel Edition Icon added
    [PLsi.ods]
2020-09-19 Green Arrow instead "SAVE"
    [PLsi.ods]
2020-09-21 Creating LadderEditor screens
    [PLsi.ods]
2020-09-22 working on Ladder Editor screens
    [PLsi.ods]
2020-09-25 Ladder Editor draw Menu completed
    [PLsi.ods]
2020-09-28 Ladder Editor - Edition of boolean instructions
    [PLsi.ods]
2020-10-04 Ladder Editor - DELETE function added
    [PLsi.ods]
2020-10-05 Ladder Editor - Column Element Editor
    [PLsi.ods]
2020-10-17 reduced to 400 networks due to Heap issues
    [PLsi.h, diskManagement.cpp, drawNetwork.cpp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]
2020-10-18 Migrated to FFat (SPIFFS removed)
    [PLsi.ods]
2020-10-18 clean up for V0.0
    [PLsi.ods]
2020-10-24 Ladder Editor - Working on Timers & Counters
    [PLsi.ods]
2020-10-24 Ladder Editor - Timers and Counters done
2020-10-30 Fixing #47
    [PLsi.ods]
2020-10-31 Keyboard ongoing
    [PLsi.ods]
2020-11-01 Configurations Pages added
    [PLsi.ods]
2020-11-02 HMI Configuration Pages ongoing
    [PLsi.ods]
2020-11-07 Increase Display SPI bus speed
    [PLsi.ods]
2020-11-09 WiFi Configuration page
    [PLsi.ods]
2020-11-15 Housing 3D model design
    [BOM_PLsi_0.xlsx, PLsi v0 - Assembly rev G.3mf, PLsi v0 - Board rev A.3mf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]
2020-11-15 Housing 3D design
2020-11-19 Housing Base rev C added
    [PLsi v0 - Housing Base rev B - CURA.3mf, PLsi v0 - Housing Base rev B.3mf, PLsi v0 - Housing Base rev B.stl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]
2020-11-19 Housing Base rev D added
    [PLsi v0 - Housing Base rev C - CURA.3mf, PLsi v0 - Housing Base rev C.3mf, PLsi v0 - Housing Base rev C.stl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]
2020-11-23 Housing Design v0 completed #54
    [PLsi v0 - Housing Cover rev A.3mf, PLsi v0 - Housing Cover rev D - CURA.3mf, PLsi v0 - Housing Cover rev D.3mf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]
2020-11-23 Housing design completed #54
    [PLsi v0 - Assembly rev G.3mf, PLsi v0 - Board rev A.3mf, PLsi v0 - Housing Base rev D - CURA.3mf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]
2020-11-26 Housing v0 with Pen support added
    [PLsi v0 - Housing Cover rev D - CURA.3mf, PLsi v0 - Housing Cover rev D.3mf, PLsi v0 - Housing Cover rev D.stl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]
2020-11-28 Menu navigation revamped
    [PLsi.ods]
2020-11-30 Web Firmware Update completed - Close #13
    [PLsi.ods]
2020-11-30 Show Current Firmware in Firmware update Page
2020-12-19 Touch UP/DOWN/PRESS / detection
    [PLsi.ods]
2020-12-23 User HMI buttons screen
2020-12-24 HMI first "fix" version - Close #36
    [diskManagement.cpp, hmi.h]
2020-12-24 Fix - Show firmware screen after web update
    [hmi.h]
2020-12-26 organize doc
    [PLsi.ods, PLsi.xlsx]
2020-12-26 Documenting project
    [PLsi.ods]
2021-01-01 estimated cost file updated
    [PLsi v0 - estimated cost rev0.xlsx, PLsi_v0-estimated_cost_rev0.xlsx]
2021-01-01 Update documentation
    [PLsi_comparison.ods, PLsi_general_info.ods]
2021-01-02 Wiring file added
2021-01-02 PLsi v0 wiring documentation
2021-01-02 Update pricing with TLV2462CP
    [PLsi_v0-estimated_cost_rev0.xlsx, PLsi_v0_estimated_cost.xlsx]
2021-01-02 Documentation update
    [BOM_PLsi_0.xlsx]
2021-01-30 16bit Comparison Instructions added
    [PLsi_general_info.ods, PLsi_v0_estimated_cost.xlsx]
2021-02-05 analog Input Output improvements
    [PLsi_comparison.ods]
2021-02-05 analog in filtering
2021-02-05 analog inputs filtering
2021-02-19 document PWM test
2021-02-24 update structure
    [BOM_PLsi_0.xlsx, CPU - PLsi_v0_estimated_cost.xlsx, PLsi v0 - Housing Base rev E - CURA.3mf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]
2021-02-25 include components links
    [CPU - PLsi_v0_estimated_cost.xlsx]
2021-03-21 DAC Outputs scale correction
    [CPU - PLsi_v0_estimated_cost.xlsx, PLsi_general_info.ods]
2021-03-21 getTouch() now receives Threshold and Filter
2021-09-24 Modbus TCP tests
    [PLsi_general_info.ods]
2021-10-07 Modbus TCP ongoing
    [Modbus_Memory_Tests.ods, PLsi_general_info.ods]
2021-12-12 working on manuals
    [PLsi_Tests_Modbus.ods, PLsi_comparison.ods, PLsi_general_info.ods]
2021-12-12 improving doc
    [PLsi_v0_comparison.ods]
2021-12-12 organizing doc
    [BOM_PLsi_0.xlsx, CPU - PLsi_v0_estimated_cost.xlsx, PLsi v0 - Housing Base rev E - CURA.3mf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]
2021-12-25 Working on Hardware Manual
    [BOM_PLsi_0.xlsx]
2022-01-29 New demo program for easier I/O Validation
    [PLsi_Tests_Modbus.ods, PLsi_general_info.ods]
2022-06-05 Workaround Analog Inputs issue on Esp 4.4 - Resolution to 12 bits - 4096
    [PLsi.h, local_IO.cpp]
2024-05-05 Compile with latest ESP framework
